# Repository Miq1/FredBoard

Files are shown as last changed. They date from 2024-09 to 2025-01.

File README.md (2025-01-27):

### FredBoard
FredBoard is an alternative firmware for the Irijule TheoryBoard written by [frudah](https://github.com/Frudah). It has no connection with the original Irijule firmware but was written from scratch. While using the same hardware it has a number of additional features not found in the original.

While FredBoard is closed software for now, this repository is targeting at user exchange, additional (hardware) modifications and bug tracking.

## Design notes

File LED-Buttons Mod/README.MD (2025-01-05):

# The LED buttons mod
This modification will replace the top row buttons of the Theoryboard by RGB LED-lit ones the FredBoard firmware is controlling.
Initially the left button row is serving as a reference of the note colors, whereas the right button row will indicate the color of the currently selected root note.

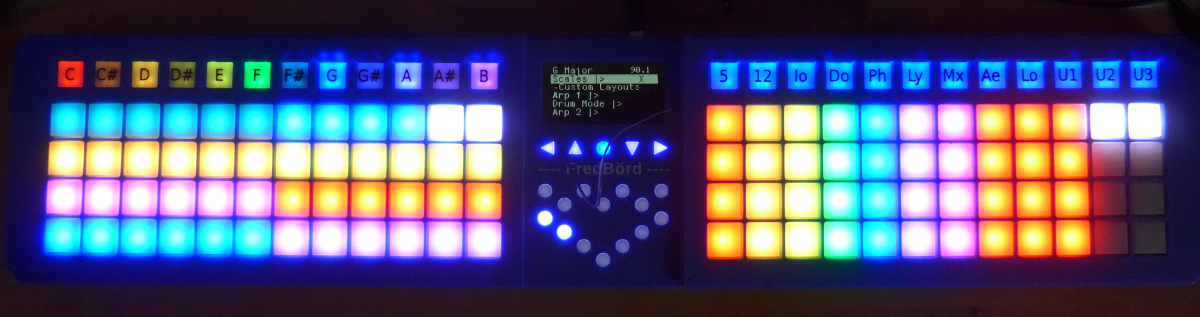
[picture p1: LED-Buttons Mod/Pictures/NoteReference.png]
Example lit board


## Some remarks before you start - please read!
This mod is a slightly complicated one and has several caveats to consider:

- it will make sense only if you are using the FredBoard firmware that controls it
- it will require some soldering skills as well as the ability to work in very small dimensions
- it will require you to solder on the Theoryboard's main PCB with a risk to damage it
- it will need permanent modifications to the Theoryboard's case - holes being cut into it
- it will cost you about 50 bucks for the materials used - more if you break something...

On the plus side you will gain some benefits:

- A much better visibility of buttons and their functions
- a case lid that is really sturdy, much more than the original
- the ability to choose a color you like
- overall a unique board no one else has

Note that this modification is including both the "Top Row Mod" and the "Center Panel Mod" in modified form.

## Update V1.1
- I modified the STLs for a better fit. All instructions remain valid, just the 3D prints are different.
- I added some pictures of the different lettering on the buttons (center/ragged left, lit/plain, main text only/second text added).

## Requirements
### Materials
#### Case lid

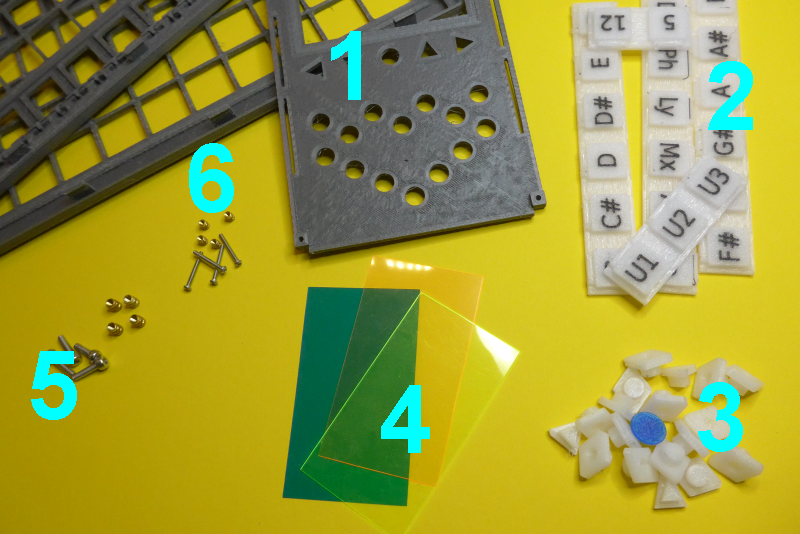
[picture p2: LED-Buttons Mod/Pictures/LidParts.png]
Materials for the lid


1. 3D printed components for the plastic lid.
Note that a 3D printer is required that is able to print a 300mm wide and 150mm deep part!
2. 3D printed top row buttons - requirements as described in the "Top Row Mod" instructions (TPU, best with IDEX printer)
3. 3D printed center panel buttons - requirements see the "Center Panel Mod" instructions
4. Screen protector/filter sheets as described in the "Center Panel Mod" as well
5. 4 M3 melt-in threads and 4 matching M3x12 screws.
Cylindrical screw heads advisable.
6. 4 M2 melt-in threads and 4 matching M2x16 screws.

#### Wiring and electronics

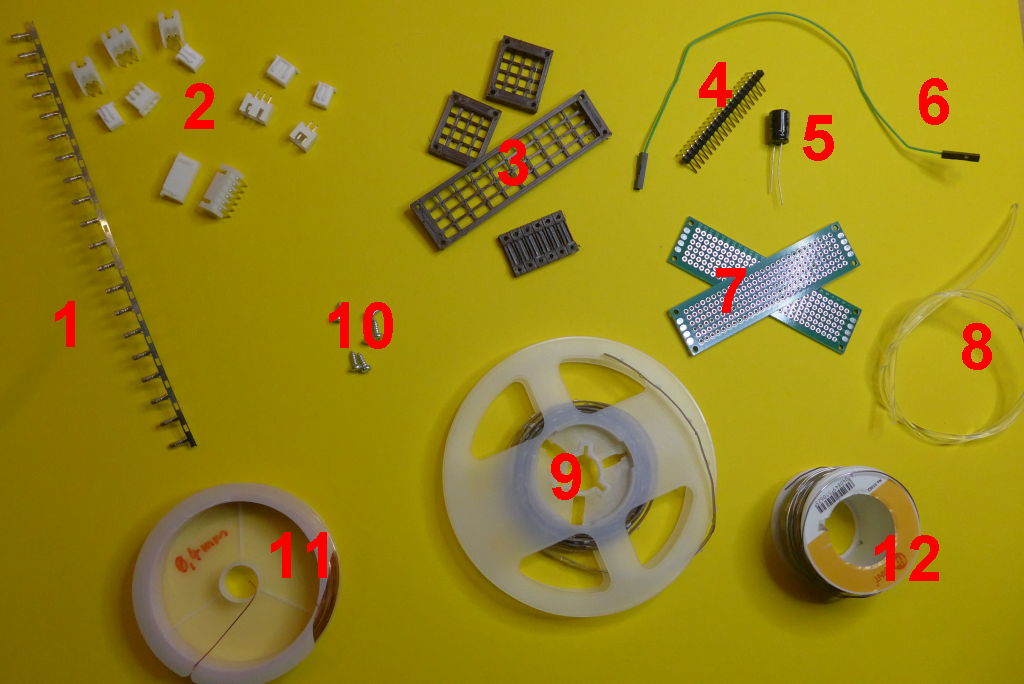
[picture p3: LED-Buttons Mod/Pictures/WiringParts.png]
Materials for wiring


1. Crimp contacts for JST XH type connectors
2. JST XH connectors 
    - board connectors (male): 
        - one 6-pin angled 90°
        - one 3-pin angled 90°
        - two 2-pin angled 90°
        - one 3-pin straight
        - one 2-pin straight
    - cable connectors (female)
        - two 3-pin
        - three 2-pin
        - one 6-pin
3. 3D printed PCB holders and cable clamps
4. some angled pin headers
5. a 470µF, 16V electrolytic capacitor
6. 20cm female/female Dupont patch wire
7. 2 2x8cm PCB universal prototype boards
8. 60+ cm of 2mm diameter PMMA fiber ("side glow")
9. 100+ cm of 3mm wide, 5V, 60 LED/m WS2812B LED stripe. 2m or more are not that expensive and will help if you break some... 
    - Example from aliexpress.com:
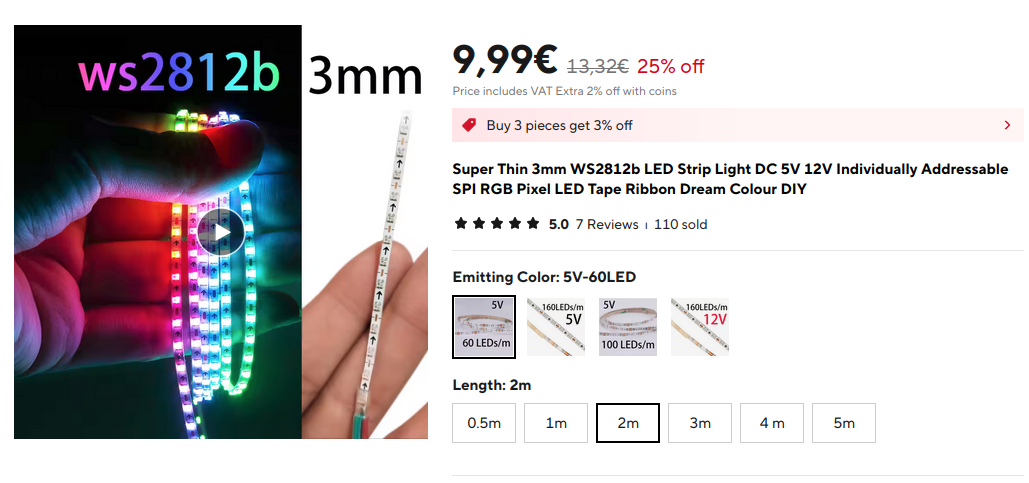
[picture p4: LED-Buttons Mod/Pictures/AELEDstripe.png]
Example LED stripe
    
10. 8+ 2.2x4mm self cutting screws
11. Enamelled 0.4mm wire
12. A good quality solder

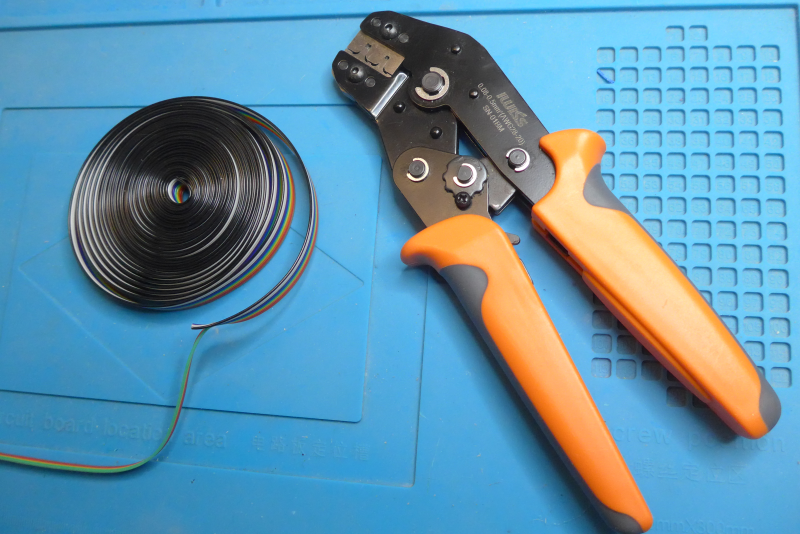
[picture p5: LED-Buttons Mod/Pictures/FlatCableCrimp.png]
Flat cable and crimp tool


* a length of AWG 24 flat cable - 5 wires at least
* (a crimp tool suitable for JST XH contacts)

### Tools
* a fine soldering iron or workstation
* a 3D printer capable of printed parts 300x150mm and able to print TPU. IDEX printer preferred for the two-color buttons.
* a multimeter for testing
* (optional) a heat gun or better a reflow workstation (recommended)
* a hot glue gun
* tweezers
* (optional) a Wemos D1 mini or NodeMCU board for testing

## Disassembly
Please refer to the "Center Panel Mod" and "Top Row Mod" instructions for the initial disassembly and removal of the printed original cover sheets on center panel and button rows.

In addition you will need to remove the PCBs. 
The center board is held by 4 screws in the corners of the board.
The two keyboard PCBs have 4 larger screws in their corners and 8 smaller ones on top and bottom of the boards.
Remove all to completely loosen the boards.
Put the screws at a safe place to later find them again...

The left and right keyboard halves are connected to the main board by flex cables.
Be careful not to bend these cables or break them! 

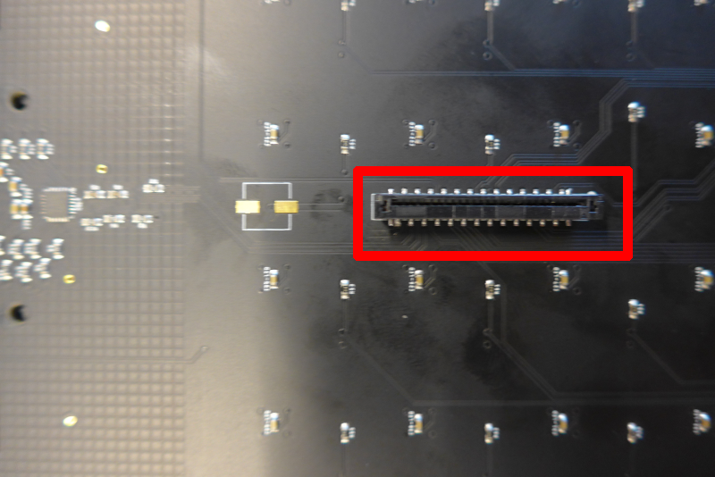
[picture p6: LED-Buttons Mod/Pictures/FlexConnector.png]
Flex cable connector


These flex cable connectors have a rectangular lock sitting around the flex cable.
To release it, gently pull the lock out of the connector.
It will not detach from it completely, but just move up a few millimeters to unlock the flex cable.
You can pull out the flex cable without force once the lock is released.

I would suggest loosening the flex cables on the main board side only and leave them connected to the keyboard PCBs to not displace or switch them.

Put the keyboard PCBs aside to a safe place.

## The Lid
We will replace the original case lid with a new, 3-part printed one.
It consists of the left and right keyboard sections and a center plate.
You will find the STL files for these parts in the "3D STLs" folder; the files are:

* ``TBLid-LeftKB.stl`` for the left,
* ``TBLid-RightKB.stl`` for the right keyboard halves and
* ``TBLid-Plate.stl`` for the center panel

You may print these parts with any hard filament you like, I recommend using PETG or even ABS for better UV resilience.

Note that lighter colors will tend to let the LEDs shine through. 
I suggest to put some black acrylic paint over the affected areas to reduce the effect:

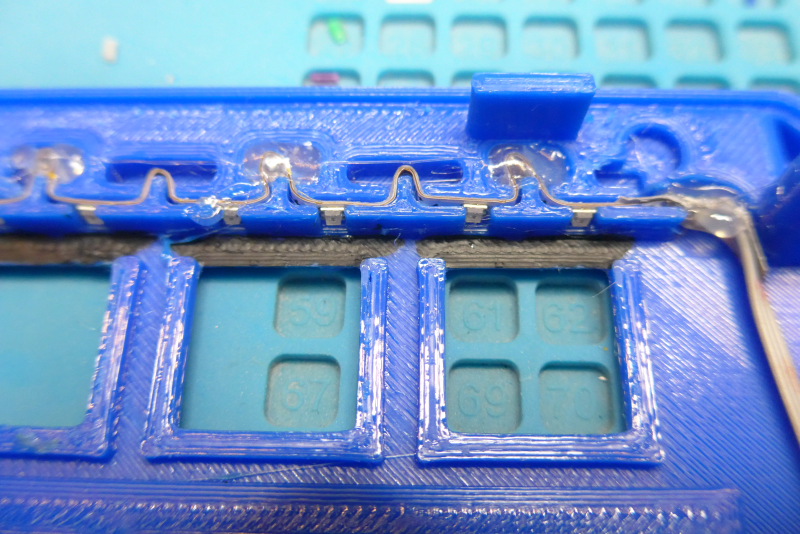
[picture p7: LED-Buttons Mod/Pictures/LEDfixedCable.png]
Areas painted matte black


Note also that the center panel has two long slits on either side that will match the two rims in the keyboard parts.
With the final assembly we will join all three parts with these.
Do not try to join the parts prematurely (before the LEDs are installed) because the fit is **very** tight and may not be loosened again without breaking it.

Finally insert the melt-in M3 threads into the 4 cylindrical columns (2 each on either lid half).
Be careful not to deform these columns when warming up, they need to fit into the corresponding holes in the lower case tray.

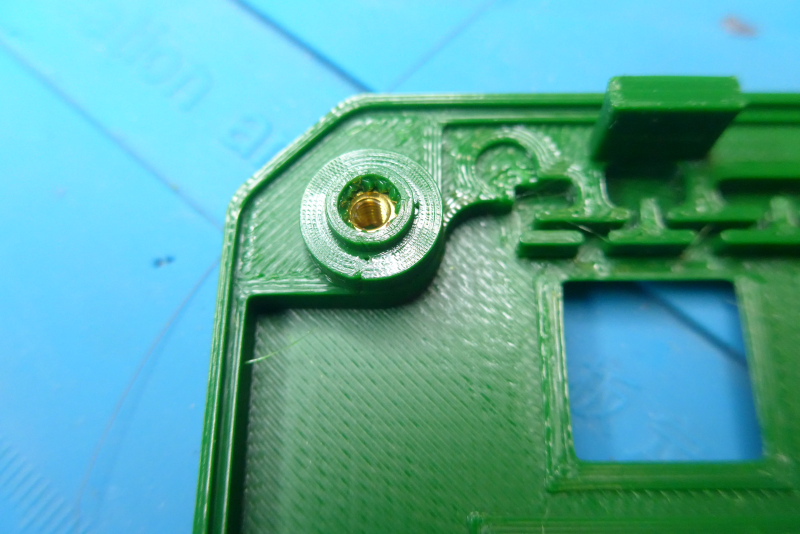
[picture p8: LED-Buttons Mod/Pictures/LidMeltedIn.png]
Threads melted in the lid


## The Buttons
As is described in the "Top Row Mod" and "Center Panel Mod" instructions, print the buttons from TPU filament to keep them flexible. 
Print the center panel buttons in any translucent color you like, as the LEDs beneath it are all white. 
A translucent white TPU is highly recommended for the button bases to let the colored LED light shine through unmodified.

### OpenSCAD Script
In the "3D STLs" folder you will find an OpenSCAD script named ``LitButtons.scad``.
You will need to install the OpenSCAD tool to use it - it is Open Source and can be found at [the OpenSCAD Home page](https://openscad.org/downloads.html).

Be sure to have the Customizer visible in it; it can be displayed with the 'Customizer' entry in the 'Windows' menu.

In the Customizer you will find all modifiable parameters to generate the buttons to your liking:

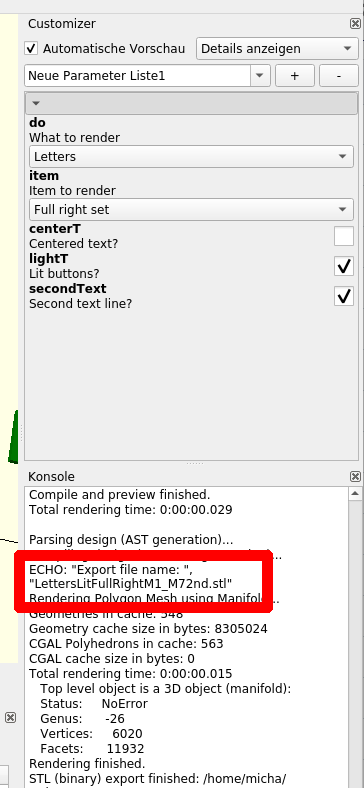
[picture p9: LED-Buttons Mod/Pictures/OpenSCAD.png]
Customizer menu


``do`` needs to be set to both 'Letters' and 'Buttons' to generate the two respective STL files in a separate run each.

``item`` lets you choose which set of buttons you want to have generated.
Note that the 'Full set' items will require a printer with a print bed at least 270mm wide!
If you have a smaller printer only, I recommend to print the shorter button sets instead.

``centerT`` will have the main text centered on the buttons if the tick mark is set.
The text is left bound else.

``lightT`` should be marked for this mod. 
It will generate the necessary light tunnels etc. on the buttons that are needed for lighting.
If unchecked, buttons for the plain top row mod without LEDs will be generated.

``secondText`` will reduce the main text in size and put a right bound second text below it.
This second text is the alternative note names on the left side and a digit sequence plus 'bsp' and 'sep' on the right side. 
These are used for the FredBoard firmware in certain cases.

The rendered picture in OpenSCAD will show you the resulting objects after you modified any value.

The get a valid STL from this result, you will need to first press the **F6** key to render the objects again in a finer structure, then the **F7** key to save it as a STL.
A recommended file name based on your chosen parameters will be shown in the Console window as indicated above with the red frame.

The LEDs are placed at the sides of the buttons.
To improve the lighting the buttons have two 2mm light channels each in them that will be used to transport the light to the far sides of the buttons as well.
This is achieved by inserting short segments of PMMA fiber into the channels.

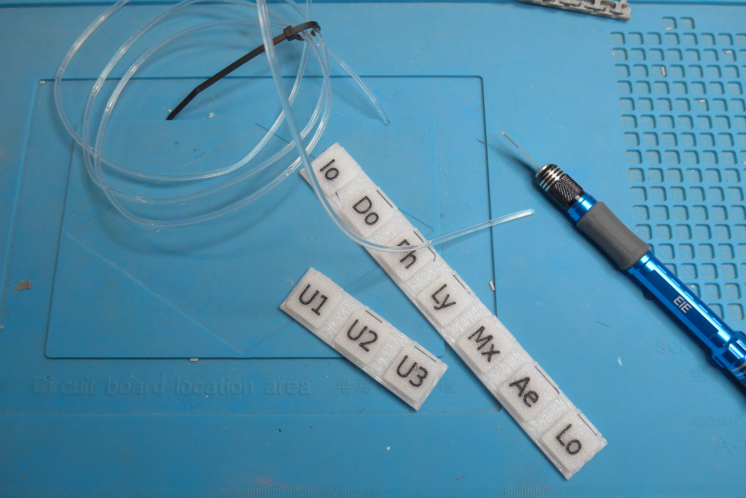
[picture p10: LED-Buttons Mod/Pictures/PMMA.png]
PMMA and tools


Push the fiber into the channel as far as possible, the cut it cleanly with a sharp scalpel.
The more even the cut is, the better the light will be passed through.

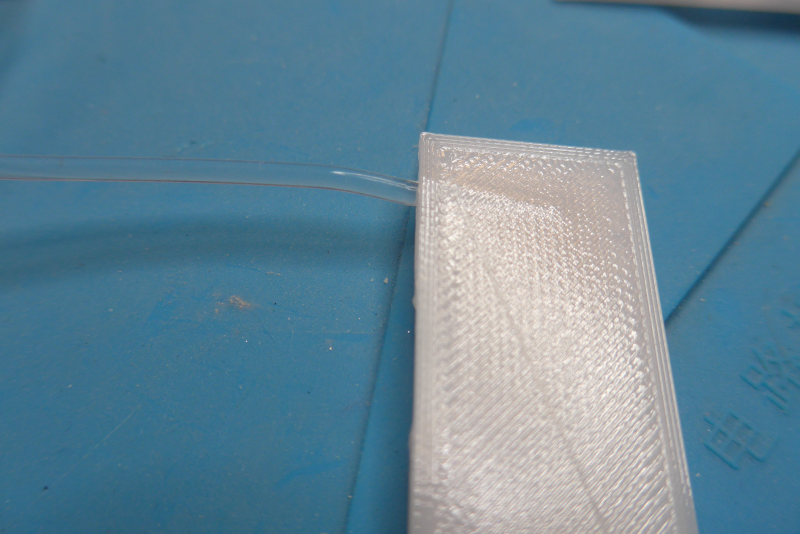
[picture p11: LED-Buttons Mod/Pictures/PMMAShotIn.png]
PMMA pushed in


Do not yet insert the buttons into the keyboard parts before the LED stripes have been installed.

## The Wiring
We will take all needed signals and power from the main board. 
With one exception all are available on solder points that are easy to connect.
These main board wires will go to a "rail board" tha sits under the main board and will distribute the signals to the LED stripes and the flash button (optional, see below).

The schematics is simple:

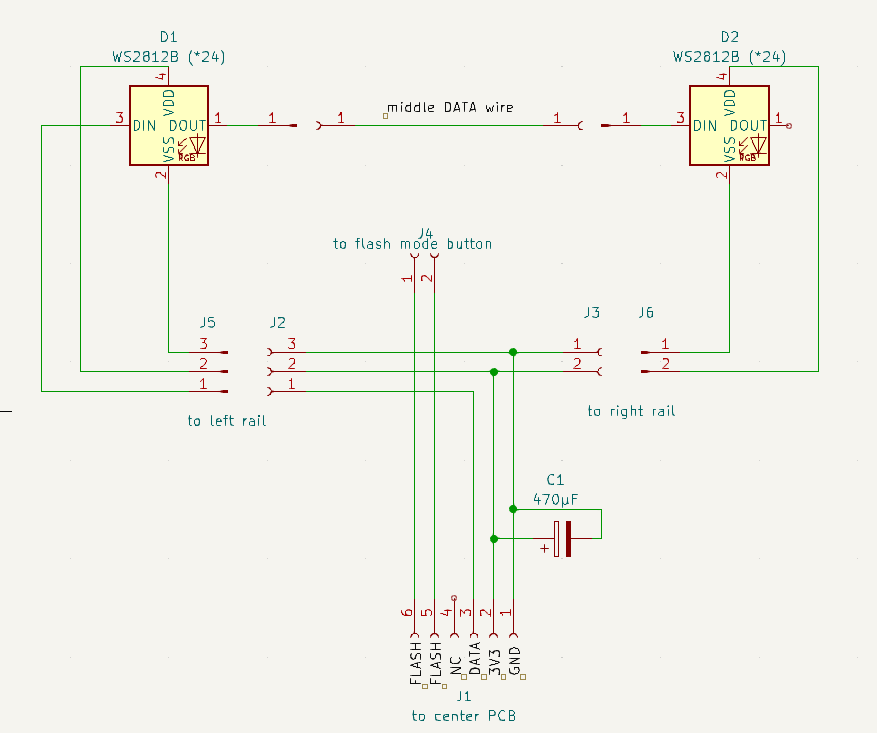
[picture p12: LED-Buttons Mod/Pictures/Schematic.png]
Wiring schematics


The connector from the main board has GND, 3V3 and the DATA IN signal for the LED stripes, plus two wires that, when shorted at power up, will set the board into flashing mode.
This is purely optional, if you do not want the flash button extension, leave out the two wires completely - but be sure to connect the other three as are seen in the schematic and wiring.

The capacitor is to stabilize the power supply of the LEDs.
Newer Theoryboards will have the same type of capacitor sitting below the keyboard PCBs (large pads close to the flex cable connector, minus is the upper pad) for the same reason.

The power lines are split into two sets of wires to supply each side independently, whereas the DATA IN line is only directed to the left keyboard'S LED stripe.

The general order of LEDs is from the far left to the far right. The DATA IN signal is guided through a single wire between the left and right stripe running below the center plate.

Keep this in mind! 
If you happen to miss this order at some point, the stripes may not work at all or at least are not lit correctly by the firmware, that is relying on the order described.

You will see that most LED stripes have arrow symbols printed on that will give the direction the stripes' LEDs are ordered. We will need the arrows are strictly pointing to the right.

### Three PCBs
We will build three small PCBs. 
One center "rail board" and two small connector boards to the left and to the right.

I am preferring designs that will allow a separation of components if necessary in the future, so all the PCBs are connected by JST XH type sockets and plugs.
You may solder the wires directly if you prefer, but I strongly advise to at least leave in the 6-pin connector between main board and the rail PCB to be able to restore the Theoryboard to almost its original state if needed.

The rail board has 90° angled JST XH connectors - else it will not fit below the main board any more.
These angled connectors are not to be found in the common sets of JST XH connectors, but must be ordered separately.
The set boxes will have straight connectors only.

**Be sure to always maintain the order of wires GND, 3V3 and DATA IN!**

#### The Rail Board
I took one of the 2x8cm prototype PCBs to set up the rail board.
This PCB will fit neatly into the lower middle compartment of the case tray (after some preparations described further down).

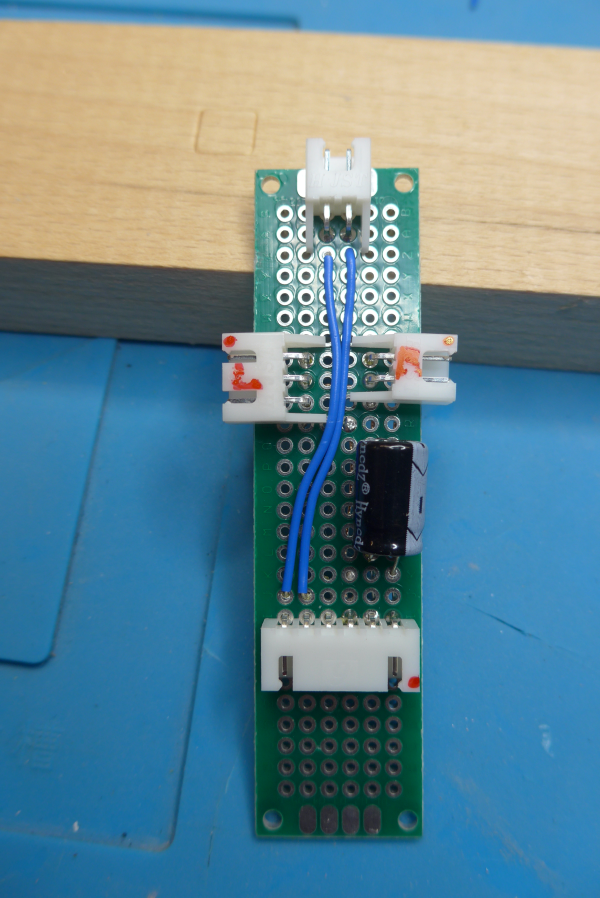
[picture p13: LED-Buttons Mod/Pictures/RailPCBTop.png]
Rail board from top

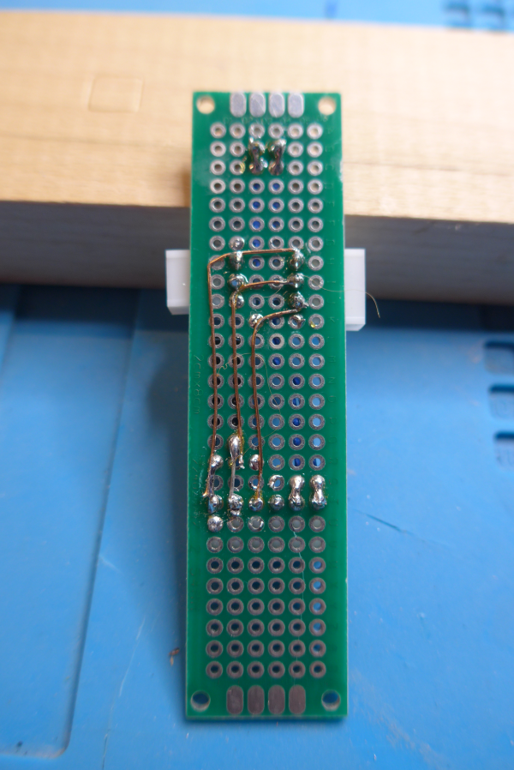
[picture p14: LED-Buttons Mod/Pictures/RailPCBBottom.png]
Rail board from below


As you can see I used enamelled wire to construct the traces. The capacitor must be placed lying sideways to again fit under the main board.

It is advisable to use the exact same layout to have the connectors accessible when the board is mounted into the case tray.

#### The Connector Boards
The left (3 pins) and right (2 pins) connector boards are very similar.
A plug and a approx. 36cm ribbon cable are the connection to the rail board, whereas the other end of the cable will be soldered to a small PCB with a matching straight JST XH connector on it.
These connectors will accept the plugs from the respective side's LED stripe.

3 PCBs

**I cannot emphasize enough to maintain the order of pins!**

I used the 3D printed cable clamps (``CableClamp.stl`` in the "3D STLs" folder) with two of the angled pin headers to secure the ribbon cables against being ripped off.
This may be overly cautious - you may decide to omit that.

I recommend to use a multimeter frequently to make sure all connections are correct and no short has been introduced.

#### Mounting Plates
I like to fix such additions to an existing device with hot glue.
In case you need to remove it again, a hot air gun is sufficient to heat the glue to get it off the ground.
Hot glue is mostly fine, but adhesion may not be the best depending of the material it is applied to.
This is why I designed mounting plates for the three PCBs that have the right dimensions to fit and have a grid structure at the bottom side to nicely be filled and held by the hot glue.

Print files are again in the "3D STLs" folder, named ``PCBsocketLarge.stl``and ``PCBsocketSmall.stl``, respectively.

The mounting plates can be fixed to the PCBs by the tiny 2.2mm screws through their holes in the corners.

### Wiring the Main Board
**This is the point where you may accidentally damage the main board - take utmost care to only solder to the points as described!**

Please see the following picture of the main board for the remarks below it:

Main board wire connections

A 12cm ribbon cable with 5 wires (3, if you do not want to have the flash mode button) is used to connect to the main board.
It is advisable to crimp the 6-pin JST XH plug before soldering the other ends to the main board to prevent strain on the freshly soldered connections.
On the picture you see my colors used for the different signals:

- red for 3V3
- brown for GND
- orange for DATA IN
- yellow and green for the flash connection

With the exception of DATA IN all wires can be cut to length and soldered to the indicated soldering points.

DATA IN is available only at the indicated pin of the flex cable connector.
With a tiny drop of solder you should be able to fix the DATA IN wire to it.

I like to secure the ribbon cable with two drops of hot glue to the main board.
When routing the cable, avoid the white dots marked with a green circle around it: these are the spots where the support struts from the case tray will touch the main board.
The green vertical line is marking another support structure of the case tray that we will have to open later at exactly the spot where you laid the ribbon cable.

### Modifying the Case Tray
To make room for the wiring and PCBs the case tray needs to be opened at several places.

Note that this is irreversible as you will be forced to remove material from the case tray.

The main modifications have to be made underneath the main board:

Cutouts at the case tray

At the area marked "1" we need to cut a hole to let through the plug from the flash mode button - should you decide to want it.
You can see the (blurry) blot of hot glue where I mounted mine in the back.

The "2" marks the area where the freshly soldered ribbon cable will run under the main board.
The traversal structure needs a 1-2mm opening here to let pass that cable.

"3" and "4" are marking the inner edges of the supporting struts that must make way for our rail board.
These inner edges of the X-shaped struts need to be removed completely, making the struts' profiles to a "T" shape.
The edges have to be removed down to the bottom, making a flat surface there.

I used a Dremel tool with a cutting disc to remove all these pieces.

In addition to the modifications show on the picture we need thin slits in the blocking walls towards the left and right outer walls of the case tray to let pass the ribbon cables leading to the connector boards.

Again I used the Dremel tool to cut small openings - just one disc thickness wide and just as deep as was necessare to get the ribbon cable through.

### Placing the Boards
Now that everything is prepared we can install the three boards.

The rail board should neatly fit into the opening we created between the struts:

Rail PCB placed

Note the openings marked with red rectangles.

Now is the time to also melt in the M2 threads into the openings marked green.
These will later accept the M2 screws used to hold everything together in the middle.
Again take care not to deform the the cylindrical columns when warming those with the heated threads.

As an example for both sides see the placement of the left connector board below.
The cables are running through the opened walls, the board is placed immediately adjacent to the outer wall of the case tray.
The connector is on the side pointing outwards - when the keyboard PCBs are back in place there will be a gap leaving the connector accessible.

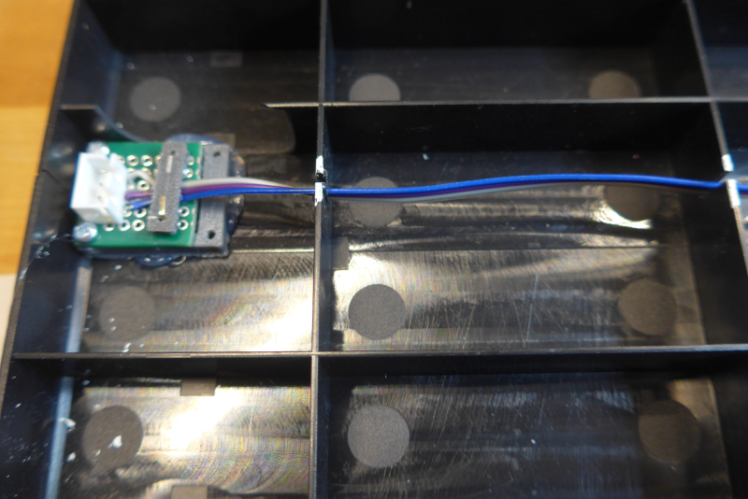
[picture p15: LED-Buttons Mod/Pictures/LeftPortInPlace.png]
Left connector board placed


(The inner wall next to the board was broken already when I got my Theoryboard...)

All three boards now can be fixed in place with a good portion of hot glue.

## Reassembly of the Case Tray
Now that the lower part of the wiring is inplace, we can put most components back together.

- reconnect the keyboard PCBs to the main board, using the flex cables. 
Be sure to use the correct orientation of cables if you had completely removed those.
The flex cable connectors' locks will fall in place again when pushing these gently towards the boards until you will feel a slight clicking movement.
- put the PCBs back into the case tray.
- use the 8 larger corner screws to fix the keyboard PCBs (4 each)
- **do not fix the main board yet**
- add the 8 bottom screws with smaller heads to additionally fix the keyboard PCBs.
**Leave off the 8 top screws (4 each) as are marked on the picture below**

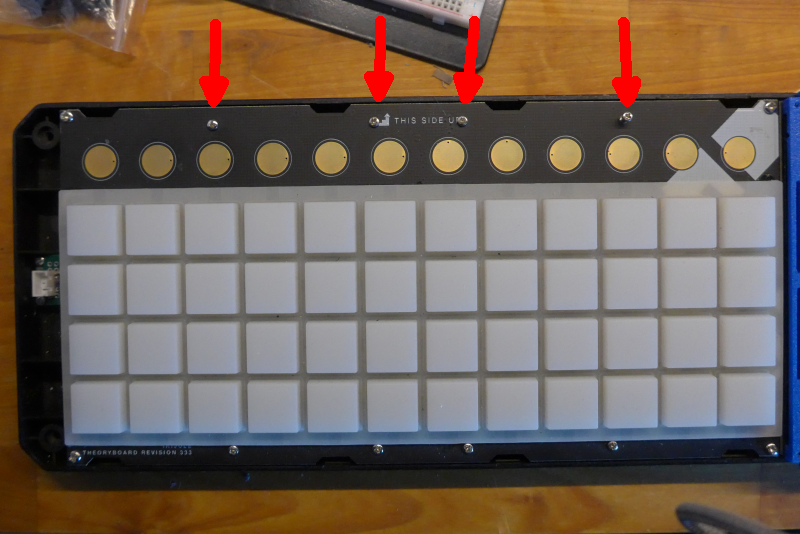
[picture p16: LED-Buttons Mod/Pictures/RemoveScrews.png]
Screws to leave off


## The LED stripes
This step is that with the most difficult procedures.
Take your time and act cautiously.

Since the LED stripe has a 60/m measure, meaning 60 LEDS are evenly distributed on one meter of stripe, their distance of 16,667mm is not suitable for the distances our board will need.

The technique used to achieve the distances for the buttons is to loop the stripe between the LEDs proper in different lengths.

The LED stripe not only is really narrow, the LEDs and their connections to the stripe are not very robust.
A single broken connection will render the stripe useless for our purpose.

Thus utmost care must be taken to not bend the stripe too close to the LEDs to prevent them to break off.
The stripe material itself is tolerating some rough treatment, though, so if you need to force a bend, do so at the plain stripe.

As said before, the stripes have a direction, indicated by arrows printed on the stripe.
You need to maintain a direction of left-to-right (if seen from above the Theoryboard) throughout the stripes' installation.
**You will have to install the stripes from the bottom side of the lid parts, so keep in mind the directions will be reversed!**

### Wiring the Stripes
For each stripe we will need 24 LEDs. 
These 24 LEDs must be consecutive on a piece of stripe that is native - no modifications made to it.
I have to explicitly state that as I learned that the vendors seem to join shorter pieces of stripes to form a longer one by soldering them together.
On the picture below the red arrow is pointing to such a soldering point.
We can not use these mended stripes as they will tend to break when bent at the soldered joints.

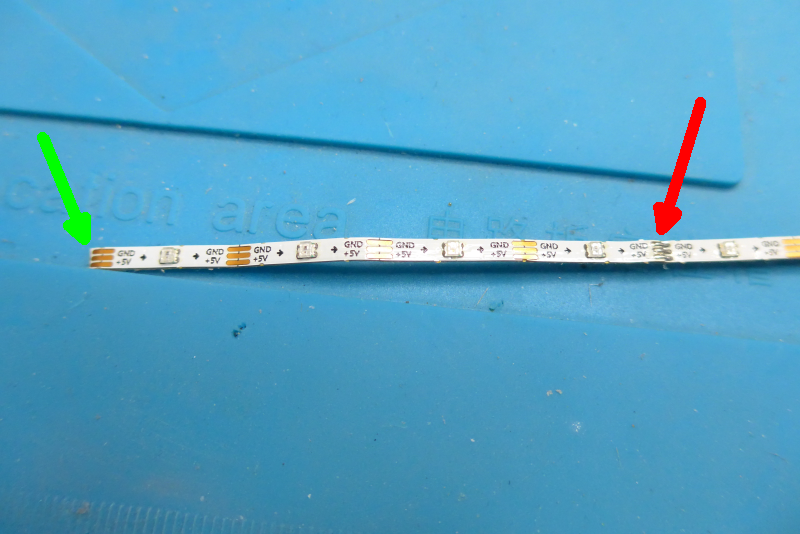
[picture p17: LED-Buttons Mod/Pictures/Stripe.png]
Example stripe


The green arrow pointing to the left end of the stripe indicates a cut made by me.
I recommend to cut at the beginning of a 3-trace contact area, hence sacrificing the LED before it.
You will benefit from the longer traces when soldering a ribbon cable to it.
Same holds true for the end of the 24 LED segment.

Note also the tiny arrow symbols on the stripe indicating the direction, and the order of signals at the connectors:

* top: GND
* middle: DATA IN
* bottom: +5V - specified voltage, we will be using 3V3

I strongly advise to cut, tin, trim and crimp the cables before soldering these to the LED stripe.
Even if you may lose the work when breaking something afterwards, preparing the cables will protect the stripes from being broken by rough treatment.

#### Leftmost Cable
On the far left side we have a 3-wire ribbon cable that will be plugged into the left JST XH socket and connect to the left end of the stripe on the other end.
A 9-10cm length of ribbon cable will be sufficient to connect to the socket.

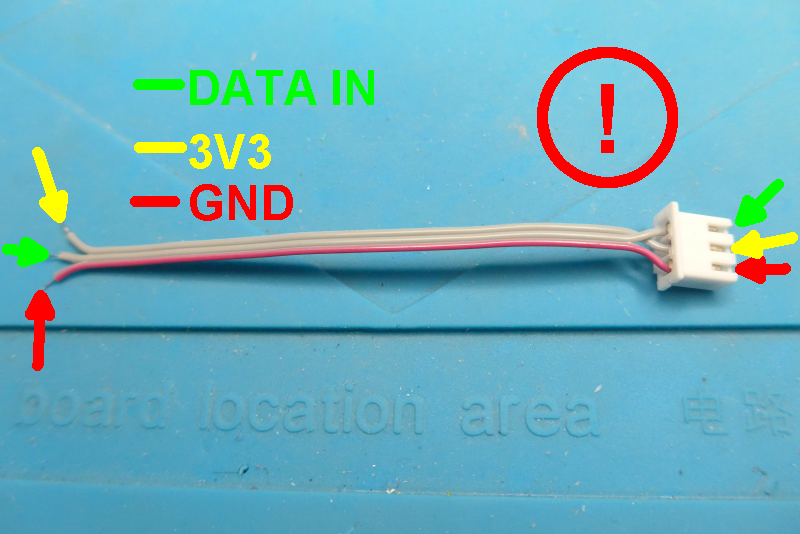
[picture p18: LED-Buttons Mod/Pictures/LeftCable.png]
Cable for left stripe on left side


**Note that the DATA IN and 3V3 wires need to be crossed at the connector to maintain the order of the internal wiring!**

Having the prepared cable ready as seen on the picture, first with a hot soldering iron tin the three contact pads on the stripe.
Try not to put excess tin on it to prevent a short that is hard to remove.

Soldering is best to be done with a "third hand" tool fixing the parts to be joined in place.
The connection will not stand any bending or pulling, so try to avoid these movements completely to the end of the work on it.

Next with a swift touch of the iron solder the middle DATA IN wire to the middle pad.
It does not need to be overly fixed, a small unbroken connection will do.

With a multimeter check if you produced a short between any of the three pads before proceeding.
The best way to get rid of a short is to unsolder the wire again, remove most of the tin on the pads and try again.

Next bend the outer wires to their target pads one by one and again with a swift touch fix each on the respective pad.

With the multimeter check for any shorts again.
There must be no connection between any of the pads.

#### Interlude: the Test Sketch
I found it handy to always check if the stripe was working while I was on it.
I wrote a small test sketch running on an ESP8266 MCU that will drive the connected stripe to show some test patterns.
You will find the sketch code in the "Test sketch" directory with a few explanations in the enclosed README.MD file there.

No would be the first sensible point to put it into action to see if the stripe as is will work.

#### Leftmost Cable continued
If the stripe is working, we can fix the connection to further prevent breaks or shorts.
I normally will use a drop of "Pattex Repair Extreme" glue - an acrylic glue that is viscous and will fill the tiny gaps between the ribbon cable and the stripe.
Once that is applied, I additionally will put a short piece of heat shrinking tube over the joint and let it shrink with a heat gun.

The result:

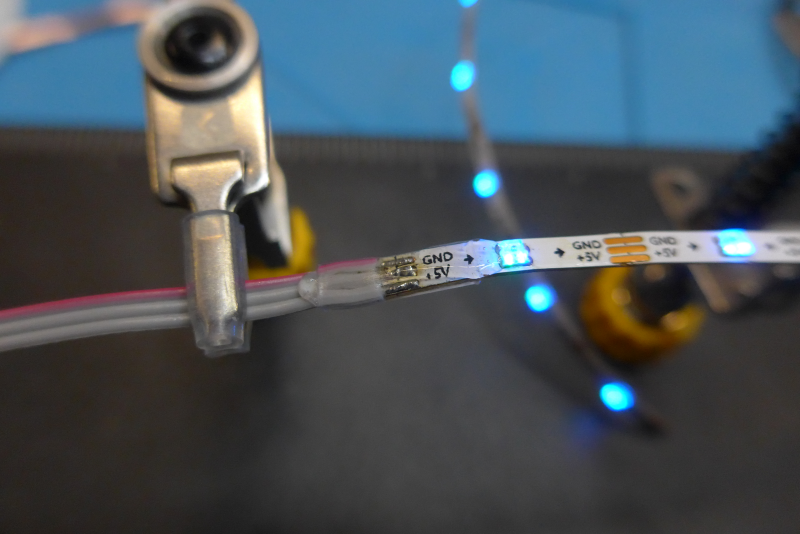
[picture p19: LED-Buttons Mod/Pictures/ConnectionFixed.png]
Connection with glue and shrunk tube over it


If you came here with success, take a break now and let the connection harden for some hours!

#### Left Stripe, Data Pin
Next we will take care of the DATA IN connection that will be located on the far side of the stripe, opposite to the connection we just made.

There we will need the middle pad on the stripe only and solder one angled pin header to it.
The longer leg of that pin header shall point out from the stripe in the direction the LEDs are facing.
In the end the single data wire across the center plate will connect here.

First of all shove another short piece of heat shrinking tube from the far end over the stripe, as you will not be able to do that any more as soon as the pin header is soldered.

Next put a little bit of tin on the middle pad of the connector at the end of the stripe.
Try to not hit the adjacent GND and +5V pads if possible.

Remove the plastic frame from the pin header, so that you get the metal part only. 
With a soldering iron put some tin on the short leg of the header.

If you have a very fine brush and acrylic paint at hand, try to cover the GND and +5V pads with it to provide a minimal isolation,
Do not touch the tinned middle pad with it.

Now with a swift touch of the iron again solder the pin to the stripe pad.

With the multimeter check if there is any short between the pin and GND or +5V.

If all is still working, you may secure the pin on the stripe with the technique as before: put a drop of glue on the joint, shove over the heat shrinking tube and shrink that with a heat gun.

Again the result:

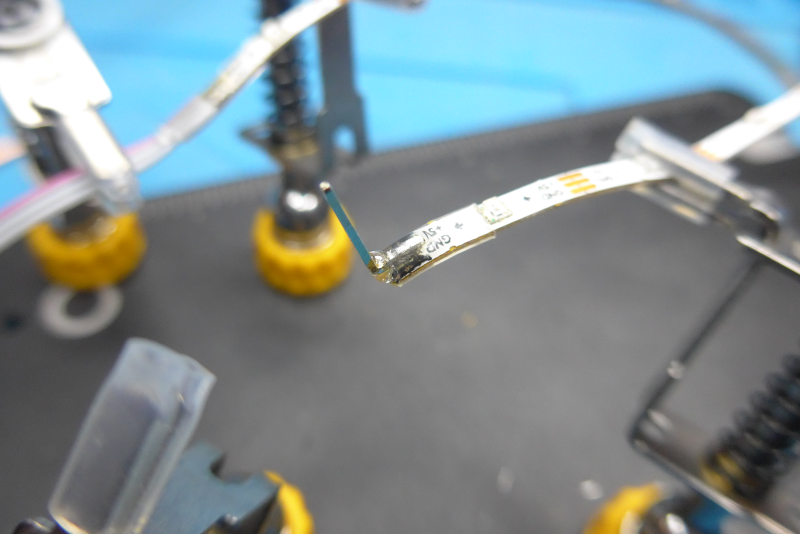
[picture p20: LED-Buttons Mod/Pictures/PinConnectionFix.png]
Header pin with glue and shrunk tube over it


#### Right Stripe, Data Pin
The right LED stripe has to have the single DATA pin on the left hand end that will get the signal from the similar pin on the rightmost end of the left stripe.

Be sure to have the little arrow symbols pointing away from the pin to get the right order of LEDs.

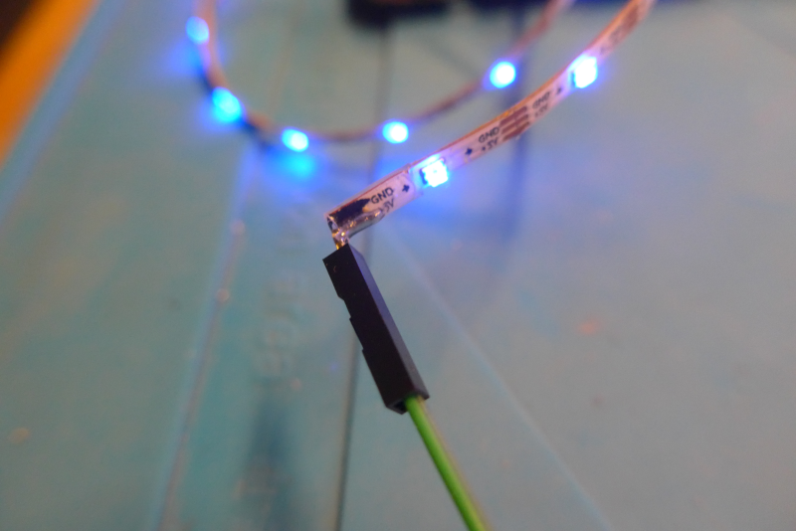
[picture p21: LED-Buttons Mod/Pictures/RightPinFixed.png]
Right stripe data pin in place


#### Right stripe, connector cable
Finally the right end of the right stripe has to get its 2-wire ribbon cable with a 2-pin JST XH plug.

The same techniques are applied here: prepare the ribbon cable including the plug first.
Take care to maintain the order of wires for the socket - GND and 3V3 must not be swapped.
Think thrice before fixing it...
Next tin the two outer pads on the stripe and cover the middle with acrylic paint if you can.
Solder the ribbon cable to the stripe pads, again checking the order of signals.
Finally - after testing the stripe - put some glue on the connection and cover it with a heat shrinking tube.

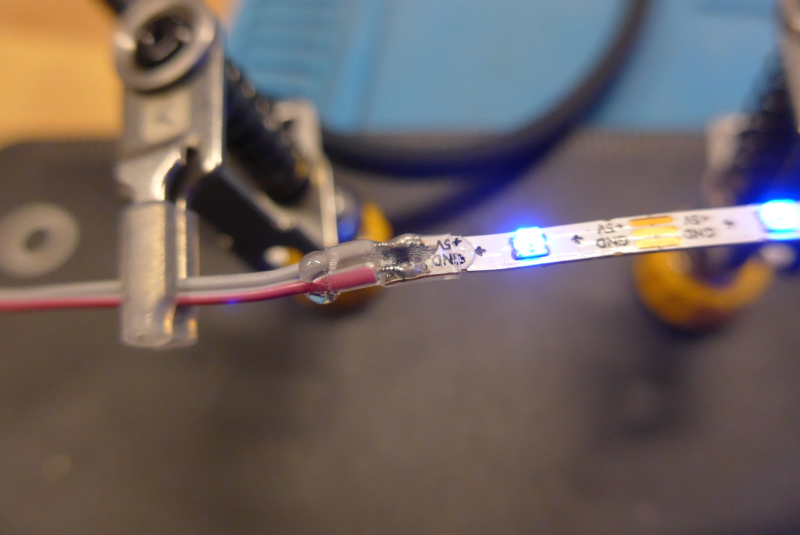
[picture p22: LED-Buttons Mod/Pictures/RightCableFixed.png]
Right stripe ribbon cable in place


### Inserting the Stripes
Now that the wiring is done, we will insert the stripes into their respective lid halves.
Remember that the left part has the 3-wire ribbon cable leftmost and the pin in the middle, whereas the right part has the 2-wire cable far right and again the DATA pin in the middle.

If you will look at the inner side of the lid parts you will notice a complicated meandering structure at the upper edge.

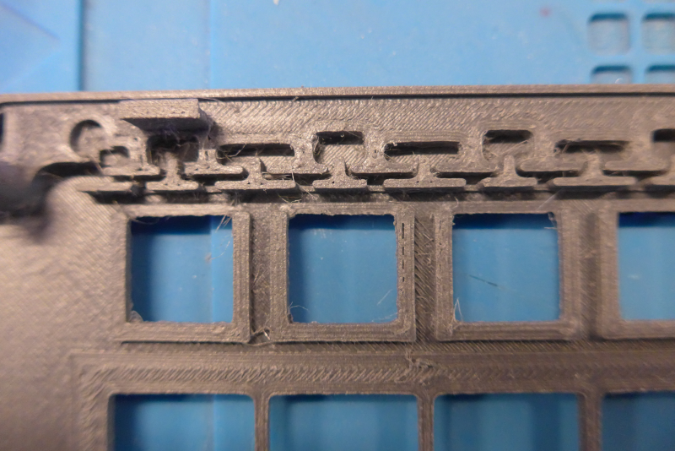
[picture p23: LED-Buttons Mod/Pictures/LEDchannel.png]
Structure to hold the LED stripe


The structure has segments shaped like a inverted "T" in the bottom row and "bubbles" on top of each T.
The T shapes have two alternating sizes, a narrower T for the spacing between the two LEDs for one button and a wider T for the spacing between two buttons.

You will notice the "bubble" on top of the narrower T always is larger than that on top of the wider T. That is because the bubbles need to hold the excess stripe material and a narrower distance between LEDs results in more stripe to be held.

Starting on one side we will insert the LED stripe in such a way that the LEDs are placed in the gaps between the Ts and the stripe will be looped through the bubbles between the LEDs.

**A word of caution again: the stripe sections immediately to the left and right of a LED must not be bent to prevent a break-off of the LED!**

I found it handy to use a small tweezer to grab and bend the stripe at the right spots in right angles, but gently push it into the structure with a finger only.
If a LED does not yet fit into its gap, gently pull the previous loop in the previous bubble a bit to set it right.
Finally I used a rounded plastic tool to push the stripe at the bent corners deeper into the structure.
At all times I let the stripe connected to the test ESP8266 to immediately notice if I had something broken.
That did happen a couple of times during development - I had to spend about 2 meters of LED stripe until I had finished two complete sets.
I got better over time...

When the stripe is set into the structure, it should look like on the picture below - and still be working.

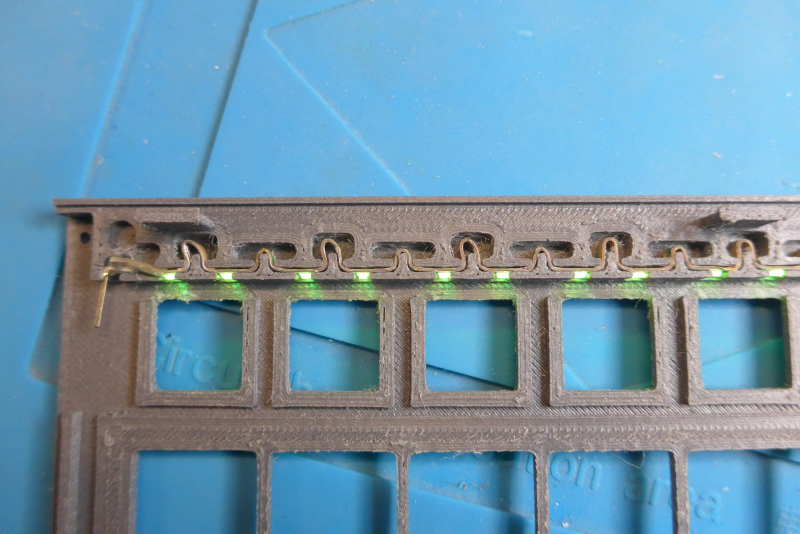
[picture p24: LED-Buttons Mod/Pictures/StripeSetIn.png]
LED stripe inserted


Finally you can fix the stripe additionally by filling the larger bubbles with hot glue:

LED stripe fixated

## Reassembly Part 2
Now you can squeeze the TPU buttons in their holes below the LEDs.
The fit is **very** tight on purpose.
The best way to get the buttons in is to first press the side with the PMMA fibers against the LED row and into the button openings.
Then with some force but carefully try to press the lower side of the buttons in.

After the procedure the buttons must be flush with the LED frame:

Buttons are even with the LED frame

Next insert the data wire into the channel on the bottom side of the center panel.
Try to have the ends of even length.
I used a rounded plastic tool to press the cable in.
It will hold without any glue.

DATA wire set into the center panel

Finally we must join the three parts of the lid.
There are two slits on each side of the center plate where the 2 edges of the keyboard parts must fit in.

The fit is overly tight on purpose, since any 3D printer will have its own tolerances.

With a flat file you will have to remove some material at the areas marked red in the picture below:

Areas marked to be filed to fit

Do not overdo - rather file, try, file again etc. until you will get a very precise fit.
depending on your printer you may have to file the inner or outer rims of the slits.
Best try first by holding the center plate in place to find which direction will suit you better.
A perfect fit will hold the parts together without any glue.
This is advantageous if you later decide to have a different center plate or need to repair one part.

If all else fails or if you feel better with it, you of course can put a few drops of acrylic glue (or whatever sticks best to the filament type you chose) on the joints to secure them.

If the parts are neatly connected, plug in the DATA wire on both keyboard sides (as seen for the right keyboard side on the picture above).

## Final Assembly
Place the screen protector/filter on the display and set all center panel buttons into their places.
Now lift the joint lid on the keyboard and connect the two ribbon cables to their sockets.
Gently nudge the lid in place:

- the center panel buttons must glide into their openings in the center plate
- the keypads must fit into the grids
- the clamps at the outer edges of the lid must go into the openings in the case tray
- the 4 corner struts with the melt-in threads must slip into the cylindrical holes of the tray

You may need to wiggle and nudge a lot until all is matching.

Use the 4 M2 screws to fix both center plate and overlapping keyboard halves to their thread down in the tray.

Flip the board over, holding the outer sides of lid and tray pressed together witch your hands.

From the bottom side fasten the 4 M3 screws into their holes in the corners of the tray.

Flip over again - it is done!

Congratulations!

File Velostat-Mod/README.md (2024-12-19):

### Why another Mod?
My original Irijule keypad on the right hand side was defective.
Over time one key ceased working.
I opened the keypad to find the cause but did not detect any obvious.
The conductive coating on the keypad foil seems to have lost its conductivity somehow.

From a former project I still had a sheet of Velostat - a conductive plastic film that changes conductivity when pressed, torn or stretched.
So I gave that a try to replace the Irijule stuff.

The result was overwhelming!
The sensitivity was massively improved, the pressure spans a wider range than the original material.
So I converted both keypads to Velastat pads now and would like to share the way it has been done.

#### Update: 3M adhesive
While the mod as described was working nicely, I had a special issue with it. 
When modding I tend to open and close the Theoryboard multiple times.
Since the key pads are made from silicone, the adhesive tape I used to fix the Velostat on it is not sticking strongly, rather like a Post-It&trade; note.
Therefore the Velostat bit came off sometimes.

I found a special 3M double adhesive tape to get around that issue.
It unfortunately ius rather expensive but nicely does its job.
The "3M mod update" was added at the end of the page.

```diff
- Note: the sensitivity curve of Velostat makes it tricky to play with velocity and aftertouch.  One can adjust to it, but the planned sensitivity  control in FredBoard will make it easier!
```

The mod is easily reversible!

### Bill of Materials
- A **sheet of Velostat**. The material is also known as Linqstat (from another manufacturer). The Net has sources; [Adafruit are selling it for about 5$ per sheet](https://www.adafruit.com/product/1361), the size is sufficient for modding 3 or 4 boards easily.
- **Carpet tape**. Get a roll of the thinnest double sided tape you can get. Your local hardware shop will have a variety.
- **Textile duct tape**. I used 19mm wide tape from Tesa, but other brands will do. 
- **Some tools**: scalpel, tweezers, scissors, ruler.
- a **plectrum** to open the TB case.
- a **7mm square hand punch tool**. These are sold cheaply in sets from China - see Aliexpress or Amazon for it. 

Optional:
- a **cutting machine** to cleanly cut the 96 sensor pieces.
- a **heat gun** or **reflow workstation** to form the sensors.

### Disassembly
#### Opening the TheoryBoard
Put your TB on a flat surface where it is completely supported.
Turn it upside down.
Remove the 4 screws at the four corners.
Turn around the board, safely store the screws for later reassembly.
With a thin plectrum or other plastic tool to open smartphones or tablets carefully slide along the slit between upper and lower part of the case to release the 10+ plastic clamps.
**Apply the least force possible, the clamps are likely to break!**
Lift off the upper case and safely place it upside down on a flat surface somewhere - it is fragile.

#### Removing the keypads
Remove the white silicone key mats. 
These have four tiny protruding bolts on the corners that go down into holes in the PCB.
Take care not to tear these off.
Now you will see the original sensor foil in place:

Original sensors

The red arrows are pointing to the spots where the sensor foil is glued to the PCB.
These glue blobs have to be cut to separate foil and PCB. 
The easiest is to slide a razor or scalpel carefully between both to cut away the glue.

Glue spot

*Note:* To revert the mod you will have to glue the sensor foil in exactly the same position.

Lift off the foil, put it in a sleeve and store it safely, lying flat for a potential later reversion of the mod.

Original sensor foil removed

Now you will see the PCB sensors and center LEDs.
Take care not to scratch or soil the golden sensor surfaces.

PCB sensors

### Making the sensors
#### Preparing the Velostat
The Velostat material needs to be attached to the silicone key mat, one piece for each key.
The pieces must have a hole in the middle to let pass the LED's light.

The key structure in the silicone is hollow in the middle and slightly domed to the sides.
The most important area for the keys to work properly is the rim around the LED hole.
Contact to the sensors is made with this rim first, gradually widening the contact area when pressing a key.

Hence the exactness of the rim is relevant for the function of the keys, the outer area is less critical.

We will cut out squares of Velostat that have a square center hole matching that of the key and are some mm wide to each side.

Since Velostat itself is not adhesive, we need to add the carpet tape to it first.
Cut a length of carpet tape and laminate it as flat as possible to the Velostat sheet - lining up to one edge.
If you got some bubbles left between tape and Velostat, you may try to prick into it with a needle  and try to flat out the bubble.
Be careful: once stuck, the Velostat is no more removable from the tape.

With a scalpel and a ruler or a scissor cut the laminated piece of Velostat/tape from the sheet to get a stripe.

Laminated with tape

Cut stripe

#### Cutting the sensor pieces
We will need 96 pieces from our laminated material.
I used these dimensions (note again that the inner 7mm is mandatory!):

Cut dimensions

I have no cutting machine available, so I cut all the pieces by hand.
First I cut 17mm x 17mm squares with a ruler and a scalpel, as precise as I could manage. 
You will see below that I did not well, but the outer border is less relevant.

17mm alignment with ruler

Next I punched out the 7x7mm holes with a hand punch tool and a hammer.
Again I sometimes missed the center a bit, the hole was shifted to the sides by up to 1mm.
Does not matter too much as well...

Square punch tools

I used these punch tools. 
The larger one is a 17x17mm square, but I found it easier to cut the squares by hand than punching those out.

#### Applying the material
Now we will peel off the liner paper from the cut out pieces and place on on each key on the silicone mat.
Be sure to align the inner hole as good as possible with the punched hole of the Velostat piece.

The material will not fit perfectly to the keys due to their domed shape.

Piece placed

Now we have two options to get the material in a better adjusted shape:
- When the board is reassembled, for some time firmly press on each key before using the board. This will bend the material over time to accept the form of the keys. I did this with one side of my board and never was urged to correct anything since.
- Use a heat gun or reflow workstation with moderate temperature (135°C is more than sufficient) to soften the material, then gently nudge it into the right shape. **Be careful not to heat the material too much - Velostat does shrink when heated!**

The heat formed piece will look like this:

Piece heated

You can see the white carpet tape shine through now where the Velostat has shrunk a little, but the form is exactly molded to the key shape.

Repeat this for all 96 pieces on both silicone mats.

All in place

As you can see, I was not very successful cutting exactle fitting square pieces, but that does not matter at all!

### Adding the bumpers
If used as is, our keypad would work already, but it will generate a lot of unwanted key presses due to the Velostat lying on the sensor surface already and being highly conductive.
So we need to separate it from the sensors by just a little bit.
For that purpose we will apply small bumper plates made from duct tape.

I cut the textile duct tape to small squares of 5x5mm.
These squares are placed on the intersections of the stripes separating the golden sensor surfaces, tilted by 45°.

Single bumper

Repeat that for all intersections and add some more bumper pieces to the outer separations as well.
Leave out the 4 corners as there the silicone bolts must snap into the PCB.
Seen in green here (I ran out of black duct tape :grinning:)

All bumpers

### Reassembly
Put the silicone mats back on the PCB.
Be sure to slide the 4 bolts on the corners into their fixing holes in the PCB.

Now you can do a first test already to see if everything is working.
Plug in your board into your PC and boot it up.
Try out each single key to see if it is working and no other keys are triggered with it.

The pieces of Velostat can be removed easily - if you find a defective one just try with a new one.

If you found everything working, get the upper case and set it back in place.
Remember the fragility of the clamps and use no force to seize it in.
If it is snapped on, turn the board and fasten the 4 corner screws.

#### Mod the Mod
Alain Blanchard had an idea that may be worthwhile considering: to improve the feel of the keys, put some soft silicone under them.
I had some 1mm self-adhesive foamed rubber lying around, so I stamped out 6mm circles and placed these on the duct tape bumpers.
I did not remove the duct tape because I was afraid the glue on the rubber would not be easily removable in case.

This is the result:

Soft pads

### 3M tape mod
There is a special 3M double adhesive tape (type 9731) that has one side with a traditional acrylic glue, but the other coated with a special silicone glue.
This tape will stick very good to both the Velostat and the silicone key pads. It is expensive, though: I had to buy a 65m roll of 14mm wide tape for 60+€, knowing I would need only 1.5m in the end. It was worth it for me, you may have to decide yourself.

The tape has two liners, a brownish paper one on the acrylic side, a transparent plastic liner on the silicone side.

3M tape

#### Additional tools used
To make the production of the almost 100 Velostat tiles easier I created some 3D printed tools:

Making tools

From the left, the grey part is called the "Press" and is used to exactly center a tile on a keypad key. 
The green part ("Cut") is to cut a tile to measure from a stripe of Velostst sandwich and the yellow ("Punch") is used to adjust the length for a commecrial punching tool.

The STL files can be found here and are named "StanzlehreRund-Press.stl", "StanzlehreRund-Cut.stl" and "StanzlehreRund-Punch.stl", respectively.

I used this [this 8mm punch from Amazon](https://amzn.eu/d/eW3AJuU), the Punch adjustment part is constructed for it.
You may have to modify it if your punch is different.
The purpose is to have the 8mm hole centered 7mm before the end of the Velostat stripe, so that it will be in the center of a 14mm x 14mm square tile.

#### Making the tiles
The steps are similar to those above, but modified to use the printed tools.
In the end the making of 100 tiles took less than half of the time than I used originally.

1. pull off the brown paper liner from a length of 3M tape and apply it to the Velostat.
Try to avoid any bubbles of air between the materials.

2. cut the stripe from the Velostat sheet, resulting in a 14mm wide sandwich from 3M tape and Velostat. 
The cleaner you will cut, the easier the further processing will be.

3. cut one end of the stripe to be exactly right-angled. 
Push it into the punch tool with the printed guide inserted.
Punching holes

4. insert the punched stripe into the cutting tool and cut it at the marked line to get a 14mm x 14mm square tile.
Cut tile

5. repeat... :wink:

#### Placing the tiles
Peel off the transparent plastic liner from a cut tile and place the tile on the "Press" tool, adhesive side up.

Place tile on Press tool

Now insert the Press tool's rod into the hole of a key.
It will follow the rectangular form and hence center the tile over the key.

Press tool set in

Firmly press the tool down to fix the tile on the key.
You may wiggle the tool a bit to all sides to better follow the domed form of the key.
Remove the tool to find the tile stuck in place.

Tile in place

#### Result
The result has all tiles at their positions, firmly sticking to the silicone.

All tiles set

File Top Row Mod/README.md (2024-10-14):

## The Top Row Mod
The choice of colors, font and haptics for the top row buttons (sensors in fact) of the original Irijule design was not optimal as far as I am concerned.
I hardly could read the buttons, especially in darker environments and the cavities were too deep to please me.
So it is time for another mod.

### This mod requires some making skills - you have been warned!
To replace the top row buttons we will need to remove the old panels, print new buttons from TPU on a 3D printer at least.
The planned lighting add-on additionally requires some soldering.

### Bill of materials
We will need:
- a **plastic spatula** to lift off the original panels
- a **hot air** gun or reflow workstation is helpful
- a **3D printer**, ideally an **IDEX** one that is able to print two filaments at a time.
- two contrasting colors of **TPU filament**. 

### Disassembly
First open the case by removing the 4 screws from the bottom side.
Lift off the lid **carefully** by sliding a plastic plectrum or spatula along the long sides of the lid and unhooking the plastic clamps that are holding the lid.

Put the lid aside, laying it flat on its face.
It is fragile, so take care.

The printed panels are glued to the PCB with a double-side adhesive tape.
With hot air (I had 135°C with good results) warm up the panels over the sensor plates.
If you do it slowly and step by step, you will be able to push the spatula between the panel and the PCB.
Gently push the spatula inside, lifting the panel.
If it is too hard to push, rather warm up some more instead of forcing the spatula in.

If you succeeded removing the plates and adhesives you will see the sensor plates:
Sensor plates

### Printing the buttons
The buttons will be printed from TPU filament.
TPU is not the easiest stuff to print, known for its "stringing" tendency that will pull out thin threads of filament when the extruder is moving.
You should know which settings are best for your choice of filament.
The TPU is profiting enormously from being dried, so if you own a filament dryer, use it!

I did not try to use other filaments like PLA or PETG.
Those may work as well, but the button dimensions (``buttonWidth`` in ste OpenSCAD file) may need to be adjusted for it.
The fitting of the buttons is as tight as can be.

The STL files for the buttons with the standard letters as were on the original plates are to be found <a href="https://github.com/Miq1/FredBoard/tree/main/Top%20Row%20Mod/Basic%20buttons%20STL"> in the 'Basic Buttons STL' directory</a>

There are sets of two STLs for each button stripe:
- **C-F**, Letters and Buttons - the left half of the left button row
- **F#-B**, Letters and Buttons - the right half of the left button row
- **5-12**, Letters and Buttons - the two left buttons of the right button row
- **M1-M7**, Letters and Buttons - the middle Mode buttons of the right button row
- **U1-U3**, Letters and Buttons - the right User buttons of the right button row

The 'Letters' files are containing the inlay letters, the 'Button' files the button stripe.
I chose a separation in the listed segments to allow for different color letters on the right hand side and to keep the size of the printed objects small to fit on smaller print beds.

See below how to use both.

#### Ideal: IDEX printer with 2 TPUs
An IDEX 3D printer is able to print two filaments with two extruders simultaneously.
This is perfect for our buttons to lay in the letters in a different color.
Any other printer able to print more than one filament at a time will be fine, too.

I will describe the procedure for Prusaslicer here - that is the one I am using.
Other slicers will do as well, but you may need to adjust the settings accordingly.

To print a strip you will need to open the Letters and Buttons files of that strip simultaneously.
Load two STL files

If you do, Prusaslicer will ask you if to combine both STLs into one compound:
Combine into compound

Answer 'YES' to that.
Now the object will be placed on the bed facing up.
On the right hand side, check if the extruders have been assigned correctly to the buttons and letters. 
If not, adjust it now.
Select colors

To get a cleaner look, it is better to print the top surface of the buttoms placed on the print bed, so we need to flip the print object over now.
Select the object and in the tool bar on the left select the rotate tool.
Rotate object

Grab the red or green handle and turn the object by exactly 180°.
If you will move the mouse pointer to the inner circle of the rotate tool while holding down the left mouse key, you will be able to rotate in 45° steps.

Next use the tool below the rotate tool in the tool bar to place it on the print bed.

Since we have two TPU filaments in use, we will have to print support structures with these as well.
TPU is sticking on TPU like hell, so we need sensible settings to prevent the supports coming out unseparatable from the button strip.
These are the settings I found to allow an "easy" (well, sort of :wink:) removal of the supports:
Support print options

#### Alternative: single TPU and manual coloring
For those not having access to an IDEX printer there is an alternative way to get colored buttons.
The result will depend on your skills, but will be functional in any case.

You will need in addition to the above:
- **acrylic paint** in a color you are preferring
- a **syringe and tip** or small **brush**
- differntly grained **sand paper**

First print the Buttons file only for the strip you like to do without the Letters file on your printer with a single TPU color.
There will be cavities in it where the letters are supposed to sit.
raw buttons print
Acrylic paint

Now take a syringe and fill it with the acrylic paint (or use a brush with it) and let the paint flow into the letter grooves.
Be sure to completely fill these without spilling too much on the outside.
Letters filled

Let it dry **thoroughly!**
I set it aside overnight to be sure it had dried completely.

Finally sand the buttons with papers in increasing granularity to remove the excess paint and get a smooth surface on the buttons. 
Expect to not be able to remove every single stain of paint.
The paint will diffuse into tiny slits in the 3D print.
You will have to live with it, unfortunately.
I am not that skilled, so my result may not be the most convincing:
Finished set

### Assembly
The buttons are pushed into the square holes of the lid from the inside.
Please be careful not to break the lid, as the buttons will sit really tight in the holes.
Push them until the button surfaces are flush with the outside of the lid and the buttons' back plate touches the inner square frames around the holes.
Buttons set in

After the buttons are all set, you can replace the lid and fasten the screws from the bottom side of the board.

### Modifying the buttons
The Letters and Buttons STL files all were generated by the OpenSCAD design in ``BasicButtons.scad``.
The relevant options to be modified all are in the first section of that file:
```
// Unilluminated upper row buttons on FredBoard

fontSize = 7;           // size of text
textXOffset = 2;        // Distance to move text right/left in non-center mode
textYOffset = 4;        // Distance to move text up
fontName = "DejaVu Sans Condensed";

// Text strings
textLeft = ["C", "C#", "D", "D#", "E", "F", "F#", "G", "G#", "A", "A#", "B"];
textLeftAlt = ["C", "Db", "D", "Eb", "E", "F", "Gb", "G", "Ab", "A", "Bb", "B"];
textRight = [ "5", "12", "M1", "M2", "M3", "M4", "M5", "M6", "M7", "U1", "U2", "U3"];
textRightAlt = [ "5", "12", "Io", "Do", "Ph", "Ly", "Mx", "Ae", "Lo", "U1", "U2", "U3"];

// 1. Make the button base 
// Use the text strings from above to generate a full set or use
// makeButtons(["one", "two", "foo", bar"]) notation to generate your own.
//
// The text vector is mandatory, optional is
//   center = true/false to center the text on a button

// makeButtons(textLeft, center=true);

 // 2. Make the letters
 // Same options as above
 // *** Be sure to use the very same options as for the makeButtons() call,
 // *** else the result will be defective!
 
// makeLetters(textLeft, center=true);

// Both must be rendered separately and exported as separate STL!
do = 1;
centerT = true;
// textString = slice(textLeft, 0, 5);   // Left half of left row
// textString = slice(textLeft, 6, 11);  // Right half of left row
// textString = slice(textRight, 0, 1);  // 5, 12
textString = slice(textRightAlt, 2, 8);  // M1-M7
// textString = slice(textRight, 9, 11); // U1-U3

if(do==1) {
  makeButtons(textString, centerT);
} else {
  makeLetters(textString, centerT);
}
```

This was written for OpenSCAD, a free parametric CAD application available for several operating systems.
OpenSCAD has a nice IDE to develop these designs, you immediately will see your changes on the screen to check.
You will need a more recent nightly version of OpenSCAD to run the design, because the ``textmetrics`` addition was added after the last official version was published (2021).
This function is used to enable the centering of text on a button.

You are not bound to the given texts at all.
with a call like ``makeButtons(["I", "am", "FB"])`` and ``makeLetters(["I", "am", "FB"])`` respectively you can put any text on the buttons you like. 

With the ``Run`` command you will execute your design to see the results (leftmost icon on the screenshot below).
Once you are satisfied use the ``Render`` command to refine the object to be exported (next icon to the right of ``Run``).
Finally use the ``F7`` key to export the rendered object to a STL file.

OpenSCAD commands

You **absolutely must** run the design twice, one time with the ``makeButtons()`` call enabled, another with ``makeLetters()`` with **exactly the same parameters** to get a set of matching Butttons and Letters STL files.

I did an alternative set for the mode buttons, to be found in the ``M1-M7_Alt....stl`` files:
Alternate Mode keys

### The Result
This is my current design - the blue TPU for the Mode keys is a bit too light to be optimal, but that was the only I had in stock.
The Result
The Result

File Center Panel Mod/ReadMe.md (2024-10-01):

## The Center Panel Mod
I always disliked the lack of haptic response from the center panel sensors and found the printed symbols too dark.
With FredBoard the lower buttons are getting new and diverse functions anyway, so the original print has no more meaning mostly.
So I decided to build a new center panel...

### A word on the sensors
The sensors are given as are, despite their shortcomings in some aspects.
Fred is struggling to get around some, but the basic principles will remain the same.

The sensors are based on Infineon Capsense :tm: chips.
These are watching the capacitive changes around 4 sensors per chip.

- the sensors are no buttons or switches, so anything possible with a proper switch (double click, holding etc.) will not work
- the chips will constantly try to adapt to the capacitive environment around the sensors. This can lead to sensors not always reacting
- if one chip is struggling, all sensors attached to that chip will be unresponsive simultaneously
- besides the 19 sensors on the center panel the 2 * 12 sensors in the top row are the same type
- the chips seem to go into a 'sleep mode' after some time. They are woken again by another sensor contact, but that will not be sent as a button press at all times. You may have to push a second time to activate it

The Result

### Bill of materials
First you will need some tools:

- gaffer tape
- a plectrum to open the TB case
- scalpel or razor blade
- a ~2.5mm drill
- a 3D printer - ideally able to print both TPU and PETG or PLA
- a soldering iron to melt in the threads

Plus some parts and consumables:

- translucent or white TPU filament
- opaque PETG or PLA filament
- a few drops of silicone adhesive (if you want to fix the color display filter)
- 4 M2 melt-in threads
- 4 M2 x 15mm screws with countersunk heads
- screen protector or color foil

### Disassembly
This will require some patience and carefulness to not damage anything you may want to put back later...

#### Open the case
Take off the top case lid by removing the four screws from the bottom side corners and *carefully* unkhooking the plastic clamps that are holding the lid on the inside. 
This can be done by sliding the plectrum all along the slit between lid and bottom case and carefully loosening the clamps one by one.

#### Remove the screen cover
Now we need to remove the printed screen cover from the center panel.
It is glued to the panel proper with a tough glue pasted on the complete surface, leaving out the display only.

Screen on

The best way I found is to start at a corner and slide a scalpel or razor blade flatly between printed screen and panel.
As soon as you can lift the edge a bit, do so and keep it under tension.
Now proceed with the blade along the edges and deeper into the opening.
Be careful to keep the blade flat to not damage the screen or panel.
Take special care of the flat display flex cable at the top edge.

A gentle stream of hot air may help, but take care to not overheat the materials.

This will take some time!

With this procedure some of the white inserts may already come from the panel. 
This is just fine, we will need to remove them in any case.

Screen off

Now use pieces of gaffer tape to dab off the glue residues.
If you repeatedly will press the tape on the glue and quickly lift it off again, the glue will rather stick to the tape than to the panel.

With the same technique you will be able to pull out all the 19 white inserts as well.

All removed

#### Lift off the center panel
Now 4 screws are accessible at the corners of the panel.
These are self-cutting plastic screws that may work with the new center panel, but I definitely do not recommend that.
The more you will loosen and fasten these screws, the wider the thread will get - finally not able to hold the screw any more.

I do recomment replacing these screws by a set of proper metric threads and screws.

1. remove the 4 screws
2. gently lift the center panel at one end - not too far! Be sure to keep the flex cables on the bottom side unharmed. The top side needs to be slid down a bit to let the USB and power sockets glide out of the case holes
3. with a hand drill slightly widen the screw holes in the bottom part of the case
4. use a heated soldering iron to set the melt-in threads into these holes. Do not force or overheat it
5. repeat at the other end of the panel to have all four threads replaced.

Melt-in set

### The new panel
The panel consists of two different components - the screen plate made from PETG or PLA, and the 19 button insets made from TPU.
You will find the STL files to print the parts right here in the files list.

Screen plate CAD

The screen plate (here seen from below) is made to slip in the four former screw cutouts at the panel's corners, thus lying flat on the panel.
The display opening has a frame around it to hold an optional color filter or screen protector and openings for the 19 buttons.

Buttons CAD

The buttons will be needed multiply, with the exception of the oval middle menu button.
- arrow left: 2 items
- arrow up: 2 items
- oval center button: 1 item
- rhombic select button: 14 items.

These buttons will be set into the respective openings in the panel, replacing the removed white original parts.

Plate PETG
Buttons TPU

### Assembly
Insert all 19 printed TPU buttons into their holes in the panel. 
You may need to cut or sand off remaining strings from the prints to have them fit exactly into the openings.

Buttons set in

If you would like to add a colour filter, cut a 43mm x 78mm piece from the filter material, it will fit exactly into the frame around the display opening.
Fix it with a few drops of silicone adhesive - to keep it in place while have it removable again.

Colour filters

Now place the screen plate over all buttons and gently slide it into place.
The buttons should go easily through their holes, the 4 corner squares must fit into the cutouts of the panel.

Finally fasten the screen plate with the M2 screws into the melted-in threads at the four corners.

Plate set

Close the lid, fasten the screws from the bottom side. 

Enjoy! :wink:

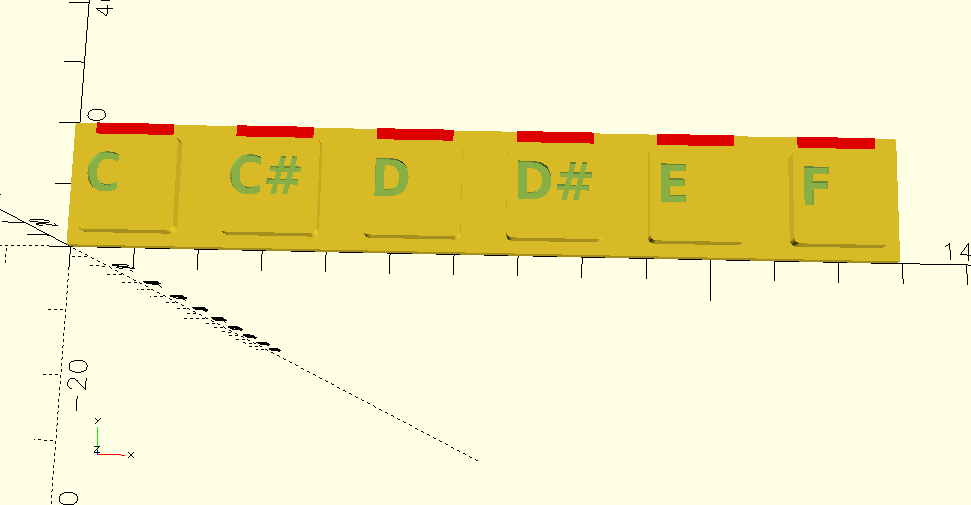
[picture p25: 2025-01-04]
LED-Buttons Mod/Pictures/ButtonsLit.png

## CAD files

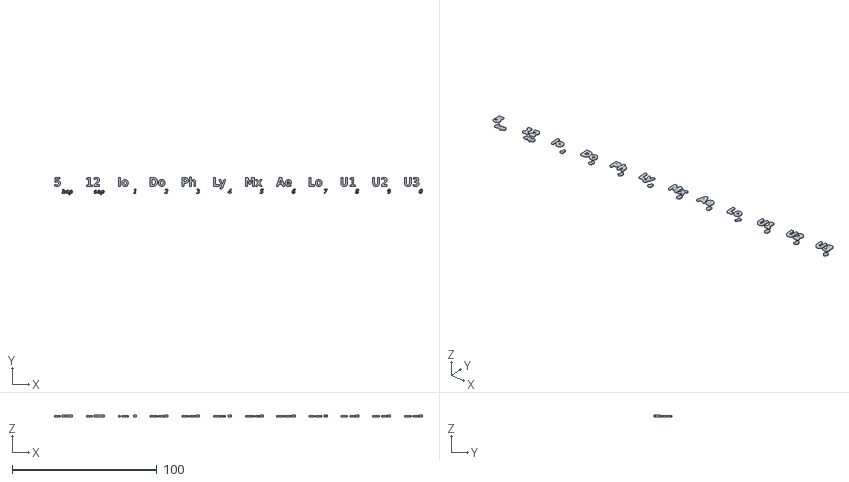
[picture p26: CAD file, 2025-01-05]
LED-Buttons Mod/3D STLs/LettersLitFullRightIo_Do2nd.stl
254.6 x 12.2 x 1.10

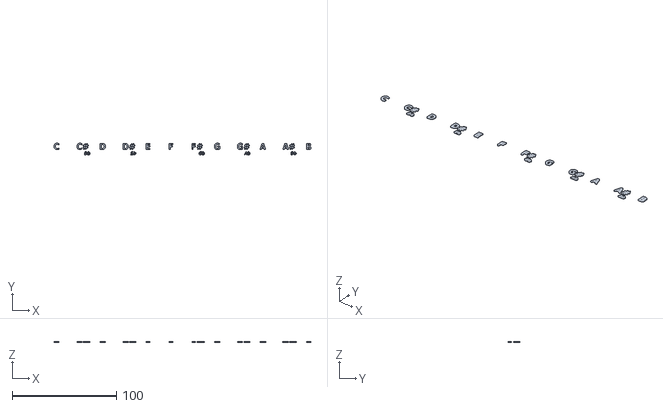
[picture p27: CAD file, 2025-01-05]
LED-Buttons Mod/3D STLs/LettersLitFullLeft2nd.stl
246.8 x 11.2 x 1.10

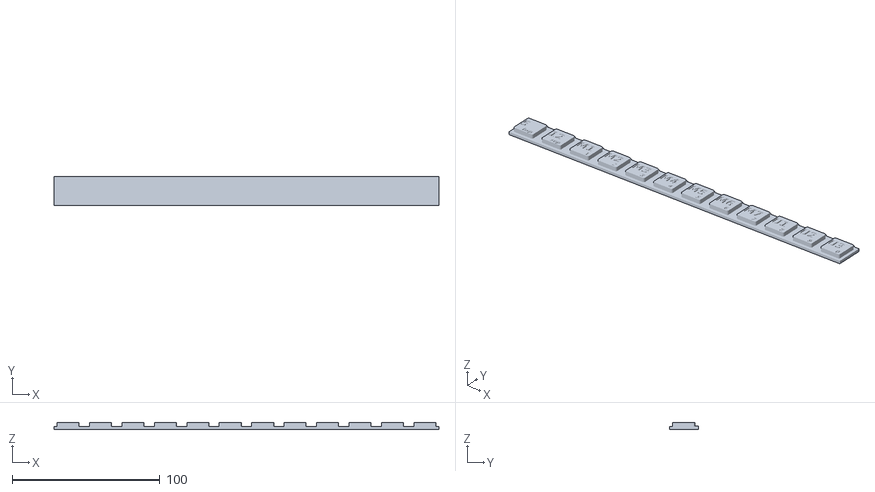
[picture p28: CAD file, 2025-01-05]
LED-Buttons Mod/3D STLs/ButtonsLitFullRightM1_M72nd.stl
261.0 x 19.4 x 5.00

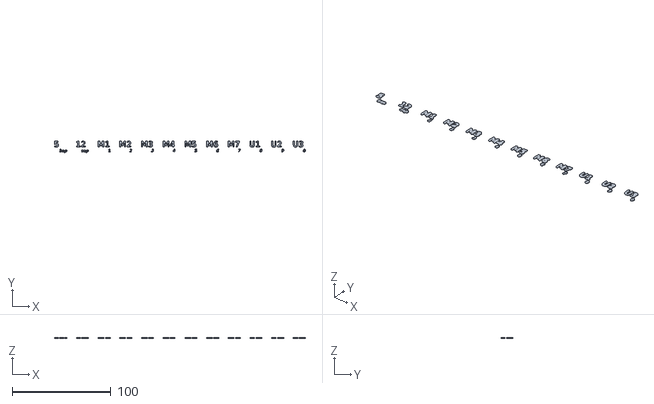
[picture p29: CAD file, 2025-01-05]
LED-Buttons Mod/3D STLs/LettersLitFullRightM1_M72nd.stl
254.6 x 12.1 x 1.10

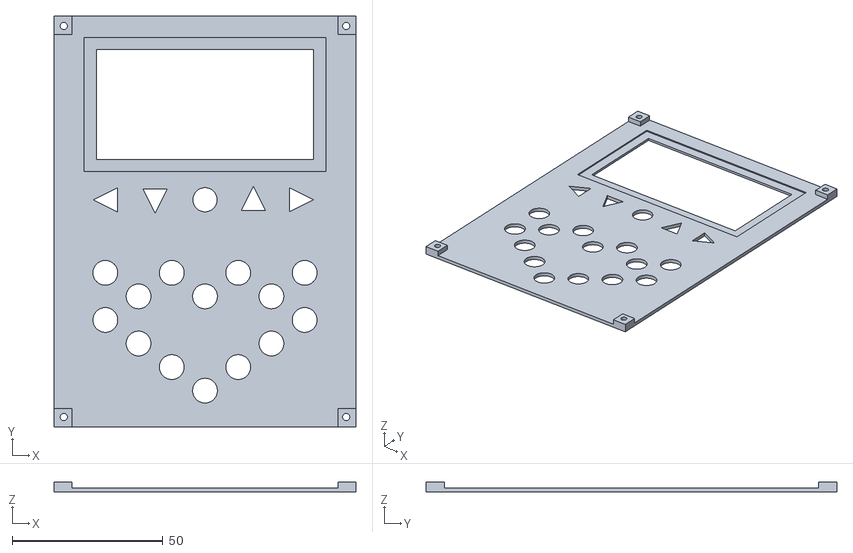
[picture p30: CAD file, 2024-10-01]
Center Panel Mod/TB-Parts-Plate.stl
100.0 x 136.0 x 3.40

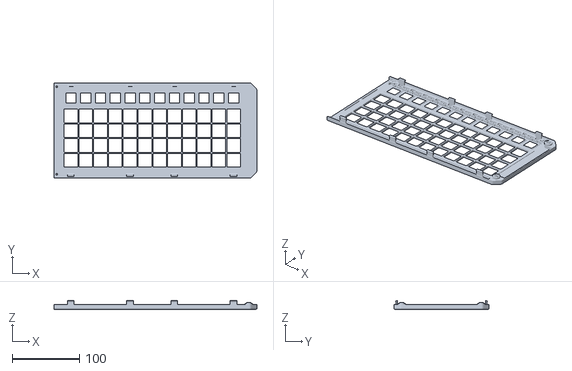
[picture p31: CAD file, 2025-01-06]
LED-Buttons Mod/3D STLs/TBLid-LeftKB.stl
302.0 x 142.0 x 13.0

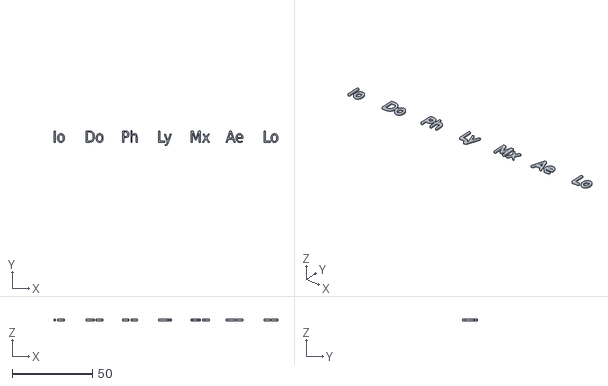
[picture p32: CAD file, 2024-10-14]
Top Row Mod/Basic buttons STL/M1-M7_AltLetters_basic.stl
139.7 x 9.41 x 1.00

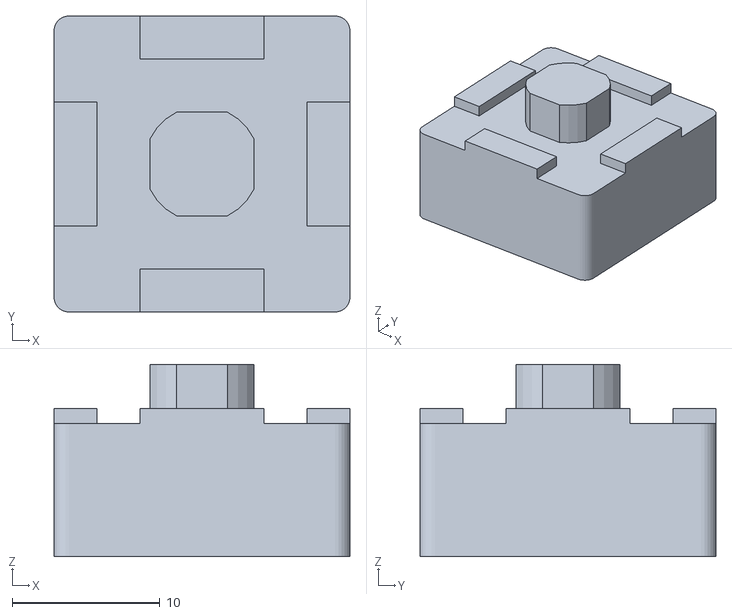
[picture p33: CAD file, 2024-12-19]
Velostat-Mod/StanzlehreRund-Press.stl
20.0 x 20.0 x 13.0

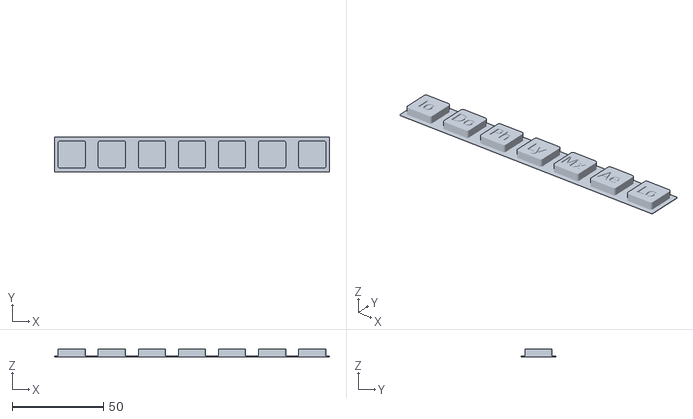
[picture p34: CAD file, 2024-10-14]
Top Row Mod/Basic buttons STL/M1-M7_AltButtons_basic.stl
151.0 x 19.0 x 4.42

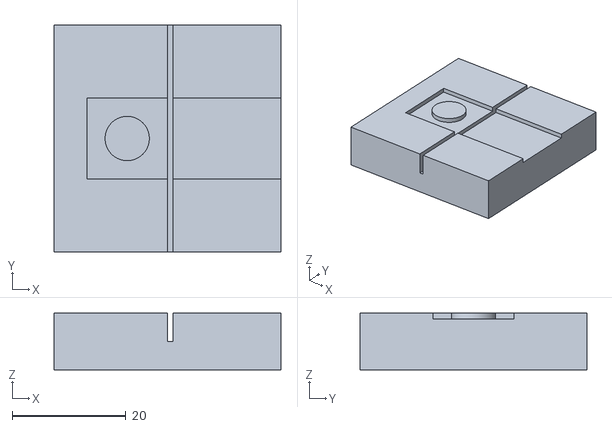
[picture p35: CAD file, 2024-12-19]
Velostat-Mod/StanzlehreRund-Cut.stl
40.0 x 40.0 x 10.0

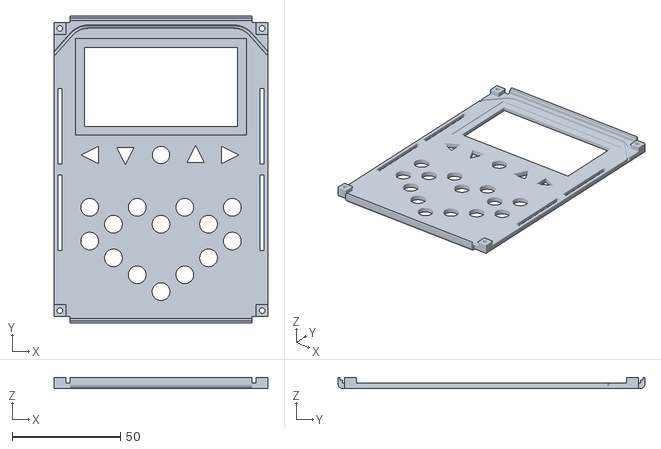
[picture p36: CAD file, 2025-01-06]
LED-Buttons Mod/3D STLs/TBLid-Plate.stl
99.0 x 142.0 x 5.00

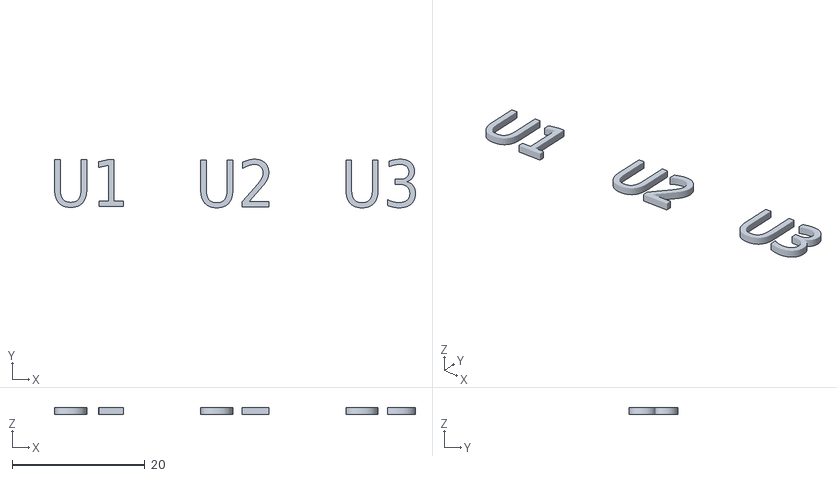
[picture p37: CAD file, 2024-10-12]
Top Row Mod/Basic buttons STL/U1-U3_Letters_basic.stl
54.5 x 7.35 x 1.00

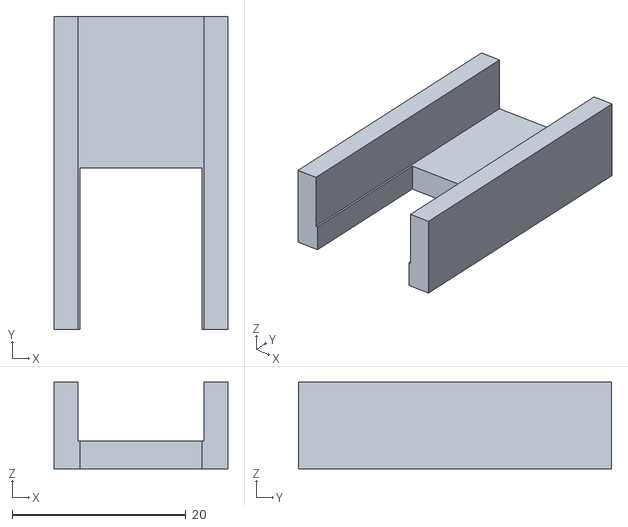
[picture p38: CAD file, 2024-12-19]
Velostat-Mod/StanzlehreRund-Punch.stl
20.0 x 36.0 x 10.0

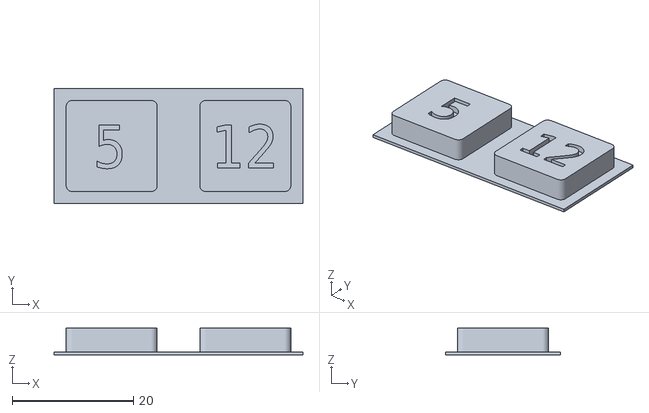
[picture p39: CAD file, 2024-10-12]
Top Row Mod/Basic buttons STL/5-12_Buttons_basic.stl
41.0 x 19.0 x 4.42

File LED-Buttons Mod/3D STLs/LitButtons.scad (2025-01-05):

// Upper row buttons on FredBoard

// Customizer variables
/* {Global] */
// What to render
do = 0; // [0:Letters, 1:Buttons]

// Item to render
item = 1; // [0:C to F, 1:F# to B, 2:5/12, 3:M1 to M7, 4:Io to Lo, 5:U1/U2/U3, 6:Full left set, 7:Full right set, 8:Full alternate right set]

// Centered text?
centerT = false;

// Lit buttons?
lightT = true;

// Second text line?
secondText = true;

/* [Hidden] */

fontSize = secondText == true ? 6 : 7;           // size of text
textXOffset = 0;        // Distance to move text right/left in non-center mode
textYOffset = secondText == true ? 6 : 4;        // Distance to move text up
fontName = "DejaVu Sans:style=Condensed Bold";

fontSize2 = 3;          // size of second text
textXOffset2 = 13;      // horizontal offset of 2nd text
textYOffset2 = 1;       // vertical offset of 2nd text
fontName2 = "DejaVu Sans:style=Condensed Bold Oblique";

// Standard text string vectors - 12 button texts from left to right in each
textLeft = ["C", "C#", "D", "D#", "E", "F", "F#", "G", "G#", "A", "A#", "B"];
textLeftAlt = ["C", "Db", "D", "Eb", "E", "F", "Gb", "G", "Ab", "A", "Bb", "B"];
textLeft2nd = [" ", "Db", " ", "Eb", " ", " ", "Gb", " ", "Ab", " ", "Bb", " "];
textRight = [ "5", "12", "M1", "M2", "M3", "M4", "M5", "M6", "M7", "U1", "U2", "U3"];
textRightAlt = [ "5", "12", "Io", "Do", "Ph", "Ly", "Mx", "Ae", "Lo", "U1", "U2", "U3"];
textRight2nd = [ "bsp", "sep", "1", "2", "3", "4", "5", "6", "7", "8", "9", "0"];

// -----------------------------------------------------------------
// All below is internal - do not change!
// -----------------------------------------------------------------
iVector = [slice(textLeft, 0, 5), slice(textLeft, 6, 11), slice(textRight, 0, 1), slice(textRight, 2, 8), slice(textRightAlt, 2, 8), slice(textRight, 9, 11), textLeft, textRight, textRightAlt];
iVector2 = secondText == true ? [slice(textLeft2nd, 0, 5), slice(textLeft2nd, 6, 11), slice(textRight2nd, 0, 1), slice(textRight2nd, 2, 8), slice(textRight2nd, 2, 8), slice(textRight2nd, 9, 11), textLeft2nd, textRight2nd, textRight2nd] : [];
iOption = ["C_F", "F#_B", "5_12", "M1_M7", "Io_Do", "U123", "FullLeft", "FullRightM1_M7", "FullRightIo_Do"];

textString = iVector[item];
textString2 = iVector2[item];
fileName = concat(do == 0 ? "Letters" : "Buttons", lightT == true ? "Lit" : "Plain", iOption[item], secondText == true ? "2nd" : "", ".stl");

echo("Export file name: ", join(fileName));

if(do==1) {
  render() makeButtons(textString, textString2, centerT, lightT);
} else {
  render() makeLetters(textString, textString2, centerT, lightT);
}

buttonWidth = 15;       // width/depth of a button
buttonHeight = 3;       // height of a button
buttonGap = 7;          // distance between buttons
buttonFrame = 2;        // outer rim around buttons
roundRadius = 1;        // corner rounding radius
$fn = 40;               // rendering steps
frameHeight = 2;        // adjust panel height
lightWidth = 0.4;       // additional rim for LED mounts
lightCubeWidth = 12;    // width of the extruded light guiding cube
lightTunnel = 1.1;      // radius of the light guiding tunnels
lightDistance = 9.2;    // narrow distance between LEDs
lightHeight = 1.1;      // elevation of light tunnels
tilt = 5;               // angle to tilt the light tunnels towards the center

function slice(list, start, end) = [for (i = [start:end]) list[i]];

join = function (l,delimiter="") 
  let(s = len(l), d = delimiter,
      jb = function (b,e) let(s = e-b, m = floor(b+s/2)) // join binary
        s > 2 ? str(jb(b,m), jb(m,e)) : s == 2 ? str(l[b],l[b+1]) : l[b],
      jd = function (b,e) let(s = e-b, m = floor(b+s/2))  // join delimiter
        s > 2 ? str(jd(b,m), d, jd(m,e)) : s == 2 ? str(l[b],d,l[b+1]) : l[b])
  s > 0 ? (d=="" ? jb(0,s) : jd(0,s)) : "";

  module basePlate (buttons, light = false) {
  cube([2*buttonFrame+buttons*buttonWidth+(buttons-1)*buttonGap, 2*buttonFrame+buttonWidth + (light == true ? lightWidth : 0), frameHeight]);
}

module singleButton (textIs = "new", textIs2 = "", center = false, centerShift = 0, light = false) {
  tw = textmetrics(textIs, fontSize, fontName);
  tw2 = textmetrics(textIs2, fontSize2, fontName2);
  union() {
    difference(){
      // base form is a rounded square
      linear_extrude(height=buttonHeight)
        offset(r=+roundRadius)
        offset(delta = -roundRadius) 
        square(size = [buttonWidth, buttonWidth]);
      // ...minus the text 
      translate(center == true ? [buttonWidth/2-tw.size.x/2-centerShift, textYOffset, buttonHeight-1] : [textXOffset, textYOffset, buttonHeight-1])
        linear_extrude(1.1)
        text(textIs, size = fontSize, font = fontName);
      // ...and second text, if present
      if(textIs2!="") {
        translate([textXOffset2-tw2.size.x, textYOffset2, buttonHeight-1])
          linear_extrude(1.1)
          text(textIs2, size = fontSize2, font = fontName2);
      }
    }
    if (light == true) {
      translate([buttonWidth/2-lightCubeWidth/2, buttonWidth, 0])
        color("Red")
        cube([lightCubeWidth, buttonFrame + lightWidth, 0.6 ]); 
    }
  }
}

module makeButtons(bv = ["new"], bv2 = [], center = false, light = false) {
  buttons = len(bv);
  centerShift = 1;
  difference() {
    union() {
      basePlate(buttons, light);
      for (i = [0 : buttons - 1]) {
        tw = textmetrics(bv[i], fontSize, fontName);
        translate([buttonFrame+i*(buttonWidth+buttonGap), buttonFrame, frameHeight])
          singleButton(bv[i], bv2[i], center, centerShift, light);
      }
    }
    if (light == true) {
      for (i = [0 : buttons - 1]) {
        translate([buttonFrame+i*(buttonWidth+buttonGap), buttonFrame, lightHeight ]) {
          translate([buttonWidth/2-lightDistance/2, buttonWidth+buttonFrame+2, 0])
            rotate([-90+tilt, 0, 180+tilt])
            cylinder(r = lightTunnel, h = buttonWidth); 
          translate([buttonWidth/2+lightDistance/2, buttonWidth+buttonFrame+2, 0])
            rotate([-90+tilt, 0, 180-tilt])
            cylinder(r = lightTunnel, h = buttonWidth); 
          translate([buttonWidth/2-lightDistance/2, buttonWidth/3, 0.8])
            rotate([-90, 0, -90])
            cylinder(r = lightTunnel, h = lightDistance); 
        }
      }
    }
  }
}

module makeLetters(bv = ["new"], bv2 = [], center = false, light = false) {
  buttons = len(bv);
  centerShift = 1;
  for (i = [0 : buttons - 1]) {
    tw = textmetrics(bv[i], fontSize, fontName);
    tw2 = textmetrics(bv2[i], fontSize2, fontName2);
    translate([buttonFrame+i*(buttonWidth+buttonGap), buttonFrame, frameHeight]) {
      translate(center == true ? [buttonWidth/2-tw.size.x/2-centerShift, textYOffset, buttonHeight-1] : [textXOffset, textYOffset, buttonHeight-1])
        color("Green") 
        linear_extrude(1)
        text(bv[i], size = fontSize, font = fontName);
      // ...and second text, if present
      if(bv2[i]!="") {
        translate([textXOffset2-tw2.size.x, textYOffset2, buttonHeight-1])
          color("Blue")
          linear_extrude(1.1)
          text(bv2[i], size = fontSize2, font = fontName2);
      }
    }
  }
}

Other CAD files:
LED-Buttons Mod/3D STLs/ButtonsLitFullLeft2nd.stl
LED-Buttons Mod/3D STLs/ButtonsLitFullRightIo_Do2nd.stl
LED-Buttons Mod/3D STLs/TBLid-RightKB.stl
Top Row Mod/Basic buttons STL/F#-B_Letters_basic.stl
Top Row Mod/Basic buttons STL/BasicButtons.scad
LED-Buttons Mod/3D STLs/BendingTool.stl
LED-Buttons Mod/3D STLs/ButtonsLit5_122nd.stl
LED-Buttons Mod/3D STLs/ButtonsLitC_F2nd.stl
LED-Buttons Mod/3D STLs/ButtonsLitF#_B2nd.stl
LED-Buttons Mod/3D STLs/ButtonsLitIo_Do2nd.stl
LED-Buttons Mod/3D STLs/ButtonsLitM1_M72nd.stl
LED-Buttons Mod/3D STLs/ButtonsLitU1232nd.stl
LED-Buttons Mod/3D STLs/CableClamp.stl
LED-Buttons Mod/3D STLs/LettersLit5_122nd.stl
LED-Buttons Mod/3D STLs/LettersLitC_F2nd.stl
LED-Buttons Mod/3D STLs/LettersLitF#_B2nd.stl
LED-Buttons Mod/3D STLs/LettersLitIo_Do2nd.stl
LED-Buttons Mod/3D STLs/LettersLitM1_M72nd.stl
LED-Buttons Mod/3D STLs/LettersLitU1232nd.stl
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

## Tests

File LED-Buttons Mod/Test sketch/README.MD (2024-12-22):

### Prerequisites

You will need the FastLED library (compiled for the ESP8266)!

To build the test program I recommend using PlatformIO, but of course the Arduino-IDE will work.

The D6 pin must be connected with the DATA IN line of the LED stripe. The D5 ping will cycle through the test modes when pulled to GND shortly.

Test modes:

1. 2s all LEDs ON, a few set to a different color. Then 2s of OFF before repeating the cycle.

2. LEDs switched on in pairs, leaving two OFF in between

3. All LEDs blue with a yellow dot wandering through in sequence.

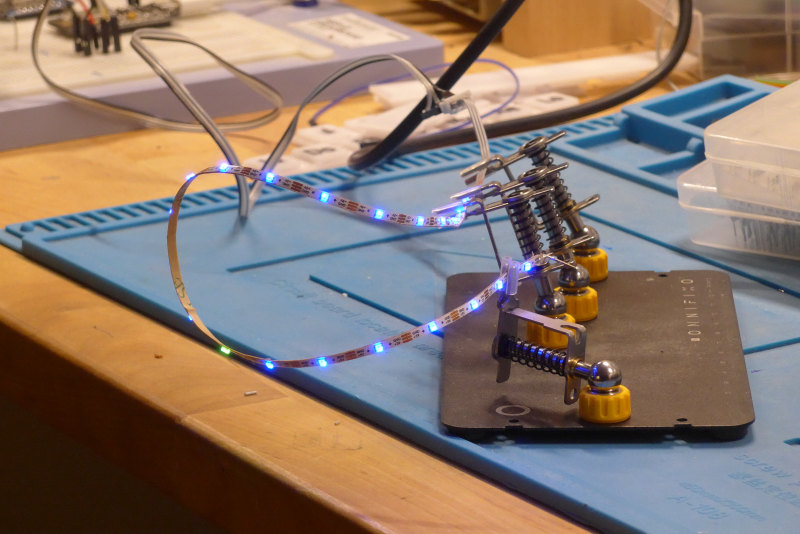
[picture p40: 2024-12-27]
LED-Buttons Mod/Pictures/TestRig.png

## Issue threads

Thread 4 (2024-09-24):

New use for rightmost 16 pads

Miq1, 2024-09-24:
The pads right of the scale notes are used to display the notes of the last pressed chord. Makes no sense to me most of the time. Except when in chromatic mode the rightmost 4 or 5 rows of pads are wasted.

What about being able to assign MIDI messages to these pads? One could switch instruments, mute and start tracks or even map one pad aftertouch to mod wheel or filter cutoff etc.

Miq1, 2024-12-08:
Outdated by the recent developments. 🎈

Closed 2024-12-08.

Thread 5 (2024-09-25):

MIDI panic does not work

Miq1, 2024-09-25:
### Version

alpha4d

### What is the issue?

The mechanism Fred described to cut off all MIDI traffic (panic) by pressing the 4 outer corner pads simultaneously seems not to work at all. I had several situations where hanging notes were not cut off.

Frudah, 2024-11-05:
This has been dealt with. Mid panic is now implemented with the two octave change buttons rather than the 4 corners. It should work in scales and classic mode. Will add to other modes shortly. Previous issue was I was sending all notes off messages on all channels, but was not clearing the active note buffers. So, the next key that was pushed would hang notes if the notes were ones that had been turned off, but not cleared in the buffers.

tracking has been improved so this should be less, if not a non-existent midi panic problem.

Closed 2024-11-05.

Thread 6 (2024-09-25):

Hanging notes

Miq1, 2024-09-25:
### Version

alpha4d (for alpha4f still valid)

### What is the issue?

When simultaneously pressing the outer 4 corner keys (to release all keys - MIDI panic) notes are triggered and left ON.

Some are releasable by pressing the same note again, others aren't.

Frudah, 2024-11-05:
Note tracking system improved. MIDI panic function improved. New method is the two octave buttons. Note tracking buffers are now being cleared instead of just sending note off messages on all channels.

Closed 2024-11-05.

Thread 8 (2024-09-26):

Switching between easy and standard chord modes requires three button presses

Miq1, 2024-09-26:
### Version

alpha4d

### What is the issue?

When in Scales mode, pressing the middle round button is supposed to toggle between easy and standard chords. It does, but only if pressed twice. Standard to easy chords needs just one press.

Frudah, 2024-11-05:
This is a feature. Previously, the first two modes were duplicated, both being chromatic chords. Now, it’s 6 chord layout, diatonic chords and chromatic chords. Two layouts will look identical, Burt the chords loaded are not. I will need to add layout names to differentiate layouts that look identical.

Frudah, 2024-11-05:
… and closing

Closed 2024-11-05.

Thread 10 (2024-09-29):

Pitchbend is not cut off with NOTE OFF?

Miq1, 2024-09-29:
### Version

alpha4d

### What is the issue?

ShowMIDI shows that the pitchbend signal is continuing after NOTE OFF.

It is disputable if pitchbend bound to a key is sensible. I can see the intention, but it at least does not fit my habits 🤣

Frudah, 2024-11-05:
Tested code was left in, since removed and verified.

Closed 2024-11-05.

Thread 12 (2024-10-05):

Note keys lighting

Miq1, 2024-10-05:
### Version

alpha4d

### What is the issue?

I find myself often wondering what octave I had set. To help me remembering I had some ideas:
- always illuminate C3 in white. Brighter, when part if the current scale, dim when not. This obviously applies to chromatic mode and otherwise scales with C in it only
- cut off lighting of notes not existing (below C-1 and above B9)
- make octave up/down keys dim if they would have no effect (since the upper row already is octave 9 or the bottom row is -1)

Smelter, 2024-11-09:
That feeds into my External LED slave strip board idea. I'll be in touch.

Frudah, 2025-02-01:
New pop-ups / screen messages will indicate octave positioning, alleviating doubt/guesswork.

Closed 2025-02-01.

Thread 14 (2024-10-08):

Install quirk / Key illumination levels / Key consistency

Smelter, 2024-10-08:
### Version

alpha4d

### What is the issue?

#### 1. LED remains lit after update and Shutdown
Shutdown via menu screen after install of Alpha4d.333
Current draw present with Bot LHS LED lit.
This is only for power down via menu shutdown after the firmware update, unplug and power up, and it does not repeat on the next shutdown.
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

#### 2.No_Hi-light
The high brightness does not change from the previous (mid?) setting.
Incremental light levels from the low end but the top two are the same.
https://github.com/user-attachments/assets/68d6743d-6e88-4873-9c1d-c24235ee1e7b

#### 3. No_Consistency
Inconsistent tones has two issues.
1) I can't get a button to repeat or another to replace it while it is sounding, its as though once triggered it holds on until the envelope is finished.
2) The buttons will trigger their LEDs without sounding for light touch, I have tried all the sensitivity ranges for a noise threshold of 21.
For the current firmware it doesn't function as a keyboard were you can just play nots reliably, which makes it not usable for live performances which has been requested elsewhere.
https://github.com/user-attachments/assets/0ebf6778-59ad-4021-8f67-db3088ed0455

Frudah, 2024-11-05:
Highlights should all be consistent. There are some places I previously set them as a constant, but I believe I have removed all constants and changed to the HighLight variable. I made sure to refresh the led buffer before the shutdown procedure finishes, so you shouldn’t see any more lights stuck on.

the other issues sounds like the note hanging/note tracking issue which has also been resolved for scales/classic.

Closed 2024-11-05.

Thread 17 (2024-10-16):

Manic MIDI Channel 1

Smelter, 2024-10-16:
### Version

alpha4g

### What is the issue?

MIDI channel 1 has continuous data output. On MIDI jack (USB MIDI yet to be tested)
(Previous channel 16 problem now solved)

Note off codes sent for C -1 and Eb-0 or 1 (digits are overlaid)

This starts immediately on power up and continues while powered up.

MIDI channel 1 sends note info to my Synth and generates an audio output.

https://github.com/user-attachments/assets/3806870a-1985-4d11-ac3a-0abb27f3659e

Smelter, 2024-10-28:
Also persists on Alpha 5

Smelter, 2024-10-28:
Also persists on Alpha 5

https://github.com/user-attachments/assets/619431fa-00e6-4820-aaec-16f8e8342737

Frudah, 2024-11-05:
This has been fixed with removing test code that was flooding the usart buffer.

Closed 2024-11-05.

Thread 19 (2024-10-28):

Alpha 4g sign off

Smelter, 2024-10-28:
### Version

alpha4g

### What is the issue?

About screen shows to be "Alpha 5". Looks like someone got ahead of themselves in the version control ;-)
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

Save settings screen has a language query. At lest the black screen of death is not shown as previous version.
https://github.com/user-attachments/assets/115739a1-19fd-4d91-945a-e3fb0ffbf0eb

Miq1, 2024-10-28:
4g is the past 😉

Smelter, 2024-10-30:
It may be the past, but it was the best version for removing the LEDs
flickering. I might just be going back to it!

On Mon, 28 Oct 2024, 16:12 Michael Harwerth, ***@***.***>
wrote:

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

Closed 2024-10-28.

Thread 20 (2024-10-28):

Flickering LEDs are back.

Smelter, 2024-10-28:
### Version

alpha5

### What is the issue?

These are LEDs on the Left Hand End under the 'C' label.
Looks like a retro step as all was well with 4g.

https://github.com/user-attachments/assets/8d77b9f2-49b6-4f30-bab1-952cadc8f248

amaskell999, 2024-11-04:
I think this has been fixed in alpha5.1.A

Miq1, 2024-11-05:
Does rather look like the DMA quirk is back Fred had earlier.

Frudah, 2024-11-05:
If you reset your settings on install of the new firmware I believe the default is 40 for noise floor. I can make the lower limit higher for roll over… or assign it to a sub menu so it allows up and down so there is no roll over. 5.1.a does fix it I believe. The buffer function is still the same. I plan on improving it. What I did find, was the strummer1 was always active and cycling and it was lagging down the led timing.

I have now made it so the strummer isn’t activated until a button with strum is pressed and is deactivated after a press. I’m sure I can optimize the strummer a bit to not make it as resource intensive later.

Frudah, 2024-11-05:
… and closed

Frudah, 2024-11-07:
I also found that strummer 2 and strummer 3 modules were continually looking to make sure there were no unresolved strum notes to turn off, robbing the chip of thousands of clock cycles per midi pulse. 5.2 has this fixed and should further reduce any of these erroneous pulses being presented.

Closed 2024-11-05.

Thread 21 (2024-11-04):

LED splatter pattern for single key press.

Smelter, 2024-11-04:
### Version

alpha5.1

### What is the issue?

I have tried multiple sensitivity and noise threshold settings with no change.

https://github.com/user-attachments/assets/e55cc6d0-6709-494d-b4df-199bfa00ce4b

Miq1, 2024-11-04:
This is a feature Fred announced with alpha5. You can switch it off in the Settings.

Smelter, 2024-11-04:
I didn't expect it to be on by default. Looks like we need a user
preference save function :-)

On Mon, Nov 4, 2024 at 4:27 PM Michael Harwerth ***@***.***>
wrote:

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

Frudah, 2024-11-07:
it is there. close to bottom of settings... select "off". put it on by default so you'd see it and can disable it if you don't like it. make sure to use shutdown function to power off. this will save settings. settings are not saved unless "shutdown" is used... or it is saved and recalled from a user set.

Smelter, 2024-11-07:
All perfectly reasonable. And yes I get it now. I know we are still at the Alpha testing stage, but when something appears, and its set on at start up, my brain says "that's new, do I like it, can I turn it off and it stays off" Consider my ramblings as innocent and exploring. I have beta tested other software and heard back that no one else has spotted that, which has lead to  interesting developments. So these are not complaints just observations.

Closed 2024-11-04.

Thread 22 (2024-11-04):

One key press, two notes sound

Smelter, 2024-11-04:
### Version

alpha5.1

### What is the issue?

Appears to be some form of "switch bounce" generated in the firmware.
https://github.com/user-attachments/assets/9d682cbc-9c11-49e7-a965-63463a2d1270

Miq1, 2024-11-04:
No bug, but a feature. Fred described it when publishing alpha5. You can switch it off in the Settings.

Smelter, 2024-11-04:
I have tried changing the sensitivity settings with inconsistent results.
The higher the numerical range the longer the gap between the initial note and the bounce note.

Smelter, 2024-11-04:
Clock set to 'E' & 'IO' clears the problem. So the setting of 'IS' is the problem!

Smelter, 2024-11-04:
Hokey Cokey?

On Mon, Nov 4, 2024 at 4:24 PM Michael Harwerth ***@***.***>
wrote:

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

Frudah, 2024-11-05:
Is this with a daw or midi instrument? Which kind please. I made the Internal Only clock because I found sending the clock to my Moog was producing issues. I may have actually been wrong, as I also found an issue with the chord note sequencers to the Moog or DAW without it.

Smelter, 2024-11-06:
> Is this with a daw or midi instrument? Which kind please. I made the Internal Only clock because I found sending the clock to my Moog was producing issues. I may have actually been wrong, as I also found an issue with the chord note sequencers to the Moog or DAW without it.

Observation is for MIDI over DIN via synth. This is my preference as I have a project waiting for key colours being declared in a SYSEX message, to have physical LEDs over the synth's keys.

Frudah, 2024-11-07:
I know you sent me a few videos. Any way you can send me the sysex messages you want? if not, can you send the video links again?

Frudah, 2024-11-09:
should be fixed for 5.2. reopen if you still have issues.

Closed 2024-11-09.

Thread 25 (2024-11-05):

Chord/ note sequencers hanging

Frudah, 2024-11-05:
### Version

alpha5.1

### What is the issue?

I don’t know who wrote this, but the chord sequencers produce hanging notes. Drum sequencer and master sequencer work properly.

Closed 2024-11-09.

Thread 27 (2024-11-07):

Key 1 in key blocks 5+6 triggered by other keys of those blocks

Miq1, 2024-11-07:
### Version

alpha5.1.A

### What is the issue?

Scales mode. The top left key in the 4x4 grid blocks #5 and #6 is lit white and stays on, if any other key in that grid block is pressed. Pressing the top left key itself will clear the white, as will any chord key on the left keyboard.

The other notes in the 4x4 block have no white indication when pressed.

Frudah, 2024-11-09:
should be fixed with 5.2. Code overhaul missed/lost some tracking variables, but they are back. Reopen if you find this is not the case.

Closed 2024-11-09.

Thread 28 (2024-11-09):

Light Board 'X' locks

Smelter, 2024-11-09:
### Version

alpha5.2

### What is the issue?

5v2a  "Light Board" setting once set won't unset locally (it will Reset) but colours are different at each stage on LHS.

Default colours on fresh install >
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

Colours when "Light Board" is selected ( 'X' ) >
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

Colours when "Reset" is run >
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

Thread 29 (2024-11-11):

Top line text overlap

Smelter, 2024-11-11:
### Version

alpha5.3

### What is the issue?

Mode line text string length needs checking for overlap with blinking filled circle.
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

Frudah, 2024-12-14:
Condensed key and scale name. Longer names may still be cut off, but priority will be given to bpm display.

Closed 2024-12-14.

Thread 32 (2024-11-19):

No Shut Down 6v0

Smelter, 2024-11-19:
### Version

alpha5.4

### What is the issue?

Alpha 6 : Shutdown menu keypress has no action.
Are the settings saved?

Menu screen will blank out after a few seconds. Missed that on the recording.

Smelter, 2024-11-25:
Progress comment from developer in 'Messenger Chat' :- "it does save before whatever it doesn't do"
So presumably its a screen menu glitch and is safe to power down after execution.

Miq1, 2025-01-07:
Pushed up to "Bug", since settings are not saved any more with 6.6.

Miq1, 2025-02-01:
'System->Save All' works now (Stechapfel.6.6.Fa)

'System->Shutdown' is bringing the board into some limbo - middle keys and display remain lit, as do the top row buttons.

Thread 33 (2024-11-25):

Aftertouch always has pressure 0

Miq1, 2024-11-25:
### Version

alpha 6.1

### What is the issue?

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
Aftertouch messages all have pressure set to 0, regardless of the pressure applied.

Frudah, 2024-11-28:
fixed 6.1

Closed 2024-11-28.

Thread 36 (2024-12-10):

Chord display flickering/invisible

Miq1, 2024-12-10:
### Version

alpha6.5F

### What is the issue?

The chord or note display screen (Main menu, left arrow button) is unreadable. There is a constant, but flickering "-2" left in the middle, while chords/notes only will shine up partly and corrupted.

@Smelter: you found it originally :wink:

Miq1, 2024-12-14:
Update on version TallFescue6.5999: The "-2" is gone, but the display still is flickering and incomplete.

Smelter, 2024-12-14:
The -2 is gone but the user name it replaced has not returned. The user name is only seen on power up when the light show that refusers to be able to turned off runs.

Frudah, 2025-02-01:
still minor flickering / screen refresh, but IMHO, readable and functional.

Closed 2025-02-01.

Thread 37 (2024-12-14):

Octave keys on right keyboard confused

Miq1, 2024-12-14:
### Version

TallFescue.6.5999

### What is the issue?

When switching root note/scales etc. the octave keys on the right keyboard will be arranged horizontally. Using "octave up" the arrangement will flip to vertically. The initial "octave down" key is dead further on, even if it is lit with a chord note or in a chromatic layout.

Miq1, 2024-12-19:
Addition: with Live Mode on, switching octaves will disable the rightmost two columns of chord note keys.

Frudah, 2025-02-13:
Octave keys should be fixed in all "Right" layouts. As always, re-open if your testing finds otherwise.

Closed 2025-02-13.

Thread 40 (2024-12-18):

Hard strike can produce multiple midi events

distrakt, 2024-12-18:
### Version

TallFescue.6.5999

### What is the issue?

I did this in "USER MODE", but likely this happens in other modes too.

A hard fast strike (like a drumming tap) can produce multiple key on/key offs. The printout below includes time stamps in microseconds. We can see it's more likely to happen on hard strike (6b and higher) and if it's very brief.

```
FRED:FB: 1642560339 90 05 6b
FRED:FB: 1642567488 80 05 00
FRED:FB: 1642571472 90 05 5d
FRED:FB: 1642744616 80 05 00

FRED:FB: 1648271776 90 16 05
FRED:FB: 1648504943 80 16 00

FRED:FB: 1664965023 90 19 73
FRED:FB: 1665178429 80 19 00

FRED:FB: 1671630723 90 19 75
FRED:FB: 1671679852 80 19 00

FRED:FB: 1674339034 90 19 77
FRED:FB: 1674390804 80 19 00

FRED:FB: 1676157987 90 19 77
FRED:FB: 1676161481 80 19 00
FRED:FB: 1676164242 90 19 46
FRED:FB: 1676204122 80 19 00
```

Frudah, 2024-12-21:
you may want to adjust the "Noise Floor" value in sensitivity. sounds like a cross talk issue fixable with adjusting the analog filter floor via the "Noise Floor" value being increased.

Miq1, 2024-12-21:
The remedy may work; it does not look like a cross talk issue, though, as it is always the same note triggered again. One possible reason could be the plastic contact sheet is slightly "bouncing" wenn hit hard enough, another would be an overflow of the velocity value when brought to the 0-127 range.

distrakt, 2024-12-21:
I'll experiment with the noise floor setting.
it does seem to be a "sometimes" thing. this morning I'm not seeing it happen. maybe i dont have enough static electricity from the day in me yet. I'll collect electrons during the day and try again.

Frudah, 2025-02-01:
should be fixed with new version 6.6Fa. please re-open if you find otherwise.

Frudah, 2025-02-01:
should be fixed with 6.6Fa. Unable to replicate in newest version. Please reopen if still occurring.

Closed 2025-02-01.

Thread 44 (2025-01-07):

Chord keys all red (numerous ways)

Miq1, 2025-01-07:
### Version

Rindfleisch... (internal)
### What is the issue?

Not repeatable every time, but when selecting a major scale, then switching back and forth between Aeolian (Minor) and Ionian (Major) sometimes all chord keys will go red:
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
These keys have no function at all.

A next switch to the other mode will restore the chord keys.

Miq1, 2025-01-11:
Happened as well when using the root key buttons. Must be something central.

Miq1, 2025-02-01:
Not reproducible any more.

Closed 2025-02-01.

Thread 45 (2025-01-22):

"5" key is a trapdoor into Pentatonic

Miq1, 2025-01-22:
### Version

TallFescue.6.5999

### What is the issue?

If pressing the "5" key once, you are trapped inside Pentatonic mode on the right hand keyboard. There is no other way out as the Scales menu.

I would expect the "5" key to toggle between Pentatonic and chromatic modes.

Side track: **if** you switched back to chromatic mode with the Scales menu, the "5" key will remain functionless until you pressed the "12" key at least once.

Miq1, 2025-01-24:
Fixed in Stechapfel6.6a, "12" brings you out of it.

Frudah, 2025-02-01:
need more info. The intention of the 5 key is to switch it permanently to pentatonic (no toggle).... with any of the modal keys, user slots... the '12' key .... or selecting a scale in the menu.

it is intended for only the user slots / '12' key to toggle back.

Miq1, 2025-02-01:
Now (Stechapfel.6.6.Fa) at least the mode buttons will bring you back.
The "12" button does change the layouts for Pentatonic mode using the same logic as in the "normal" scales - fine.
I will try to see the "5" button like another mode button for now.

Closed 2025-02-01.

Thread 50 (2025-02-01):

Note/chord display still needs some polishing

Miq1, 2025-02-01:
### Version

Stechapfel.6.6F

### What is the issue?

There are some artefacts disturbing the note/chord display (main menu, left arrow)

https://github.com/user-attachments/assets/093eac46-b89a-4900-ae11-f1047ca4274a

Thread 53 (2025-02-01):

After reboot middle buttons are all lit

Miq1, 2025-02-01:
### Version

Stechapfel.6.6F

### What is the issue?

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

I would expect the lights reflecting the last (saved) state. Pressing any of the buttons will do that.

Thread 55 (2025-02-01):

Better way to show chord notes in 'Live Update' mode

Miq1, 2025-02-01:
### Version

Stechapfel.6.6F

### What is the issue?

I would like to propose a different approach to the chord notes being shown on the right keyboard in the different layouts:

Given the chord Fmaj7 in octave 3 - notes are F3, A3, C4 and E4.

Let the note keys on the right light in white for a short period after the chord key is pressed:

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

The example is shown for the chromatic layout, but the principle will work in any layout.

This will help learning which keys are used in a chord, if the scales will remain at their root note position.

abdinfos, 2025-02-05:
Good idea but should not replace normal Live Update. Because of the isomorphic nature of the layout of the current Live Update keys layout which is also of interest in the first place. Could be a second Live Update mode.
By the way, why are the octave key in vertical layout on you drawing? It disturbs two octaves instead of one.

Miq1, 2025-02-05:
> By the way, why are the octave key in vertical layout on you drawing? It disturbs two octaves instead of one.

Fred has changed that a couple of times, faster than I could follow 😉 I do not know if he is finally decided now.

abdinfos, 2025-02-06:
On second thought, I see this more as a Chord Sense or Chord Show or whatever it's called, independent of Live Update. It could be enabled or disabled by setting.
It would come in very handy, whether for learning, guiding or even checking the operation of the chords generated by the left keyboard. For instance it could also be used to guide play by adding ephemeral notes to chords with the right hand, notes that you wouldn't have to add to chords with the center keys. Nice to vary your playing, adding a bass an octave lower while visualizing its position, guiding the melody, etc…
The pads concerned could perhaps flash as long as the notes played by the left keyboard are active (or as long as another left chord pad is pressed), or (and I think I prefer this) have a change of intensity (plus or minus).
What's more, this doesn't prevent you from keeping Live Update mode as it is now. On the other hand, if Live Update is not active, any unused keys should be used to complete the scales, making it easier to play chords, and should be taken into account by Chord Sense.

abdinfos, 2025-02-06:
> > By the way, why are the octave key in vertical layout on you drawing? It disturbs two octaves instead of one.
>
> Fred has changed that a couple of times, faster than I could follow 😉 I do not know if he is finally decided now.

I thought the octave keys were only in the vertical position with the guitar display, when in fact they are string shift keys, which makes sense

Miq1, 2025-02-06:
> I thought the octave keys were only in the vertical position with the guitar display, when in fact they are string shift keys, which makes sense

In fact they were at one time, but Fred managed to render the former octave down key useless in most other layouts 🤣
We will see what comes out at the end.

Frudah, 2025-02-13:
should be fixed now... (chord octave buttons). only the guitar layout is meant to be vertical...

will circle back on alternate live note update option.

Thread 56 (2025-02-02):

Light Board - access and use issues.

Smelter, 2025-02-02:
### Version

Stechapfel.6.6F

### What is the issue?

"Light Board" sub menu reads :
Mode : LIGHTBORD       - What are we going with here? with or without the letter A?
< Chromatic
All Lit >

Now the arrow entries in this menu are not consistent in response. I have been able to turn off all the LEDs in this menu and turn them back on.
Also I have been able to "X" and un"X" the top level menu listing.

The sub menu is time entry dependent, and returns to the same main menu position. (thank goodness, read on)
However for key entries 'O' '<' it exits to the rolling number. (can't remember what it is I read that is) press '>' and we are back to the sub menu with no time out. Press '>' at this screen and nothing happens, other than the number count is refreshed. Wait awhile and it times out back to the main menu but at the "Scales |>" entry, 8 steps up from the "Light Board |  X" entry, which if you press 'O' you are then locked into the sub menu where neither '<' or '>' works so you have to wait until the time out takes you back to the main menu.

And if that was not confusing enough. there is a surprise if you try to access the "Manual" sub menu, as you are back to the "Light Board" sub menu where pressing the 'O' key makes the sub menu title say "Scales" and further pressing of 'O' starts a scroll through colour pallet selections.

Looks like there are cross reference/links between menu entries and possible code re-use that it getting well confused.

Frudah, 2025-02-03:
Where is the button to give you the ‘Greatest bug tester award’?

Miq1, 2025-02-03:
Added it 😄

Smelter, 2025-02-03:
> Where is the button to give you the ‘Greatest bug tester award’?

Glad to be of service. Actually it's nice to use the methodical approach I used when employed, into my retirement. Just glad others know the music theory side for testing, that is what I bought the TB for, but coming without a manual and having issues, how was I to know how if it worked or even if it was doing it right?

Closed 2025-02-13.

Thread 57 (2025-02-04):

MIDI select - Cable 2 list entries shifted and one missing

abdinfos, 2025-02-04:
### Version

Stechapfel.6.6F

### What is the issue?

Settting / Midi Options / Ch out Left (or Right)
In the list, after Cable:1 Port:16 comes Cable:2 Port:2 instead of Port:1
Selecting it selects Port 1
Last entry that should be Cable:2 Port:16 is blanck but works as if normal and selects Port 16

Frudah, 2025-02-13:
Found issue. Was missing a "," in array :/   Closing. Will be fixed for next release. (post 6.6.0Fb)

Thank you for the feedback :)

Closed 2025-02-13.

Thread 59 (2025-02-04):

Clock settings - Enter settings leads to board freeze

abdinfos, 2025-02-04:
### Version

Stechapfel.6.6F

### What is the issue?

Try to enter Clock setting freezes the board
You can’t recover until you unplug

Frudah, 2025-02-05:
Fixed in my side… will be good for next upload. Will leave open until then.

Frudah, 2025-02-13:
Fixed as of 6.6.0Fb

Closed 2025-02-13.

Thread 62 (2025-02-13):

Advanced Sensitivity Settings: menu damaged

Miq1, 2025-02-13:
### Version

6.6.0 "Stechapfel"

### What is the issue?

In the Advanced Sensitivity Settings menu, the 'Offset' lines for the 2nd to 4th quarters are overwritten by a dashed line.

BTW: That menu has 22 entries. If adjusting some values for the quarters further right, one has to step through a lot of menu lines again and again if trying to see the resulting curve in between.

Two complementing solutions came to my mind:

1. After any modification of a value, show the curve until any button is pressed
2. Add another menu level like 'Quarter 1', 'Quarter 2' etc. with the respective 'Type', 'Power', 'Base', 'Offset' and 'Slope' Entries in a sub-menu.

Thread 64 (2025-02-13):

Right-side Octave keys not working correctly

Miq1, 2025-02-13:
### Version

6.6.0 "Stechapfel"

### What is the issue?

When using the "12" button to switch layouts on the right-side keyboard, funny things are happening. I was not yet able to find a rule, but you easily will get these effects after a while:
1. whole right-side keyboard muted until layout is changed again
2. octave keys vertical again in non-Guitar layouts, horizontal in Guitar instead
3. the key in the top row, second from the right is muted

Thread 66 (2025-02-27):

System/Shutdown

Smelter, 2025-02-27:
### Version

6.6.0 "Stechapfel"

### What is the issue?

6v6Fc

Selection (centre round button) of "System" blanks all the LEDs.  A given time (out) restores them.
Selection (> right arrow key) of "System" gives a sub menu where "Shutdown" is selectable,. Blanks LEDs but LCD menu remains lit with last screen.

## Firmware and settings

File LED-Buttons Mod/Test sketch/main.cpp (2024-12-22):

#include <Arduino.h>

#include <FastLED.h>
#include "Buttoner.h"

///////////////////////////////////////////////////////////////////////////////////////////
//
// Move a white dot along the strip of leds.  This program simply shows how to configure the leds,
// and then how to turn a single pixel white and then off, moving down the line of pixels.
// 

// How many leds are in the strip?
#define NUM_LEDS 48

// For led chips like WS2812, which have a data line, ground, and power, you just
// need to define DATA_PIN.  For led chipsets that are SPI based (four wires - data, clock,
// ground, and power), like the LPD8806 define both DATA_PIN and CLOCK_PIN
// Clock pin only needed for SPI based chipsets when not using hardware SPI
#define DATA_PIN  D6
// #define CLOCK_PIN 13

Buttoner toggle(D5, LOW, true);
uint8_t mode = 0;
const uint8_t MAXMODE = 2;

// This is an array of leds.  One item for each led in your strip.
CRGB leds[NUM_LEDS];

const uint16_t usedLED[] = {
   0, 2, 3, 6, 7, 10, 11, 14, 15, 18, 19, 22, 23, 26, 27, 30, 31, 34, 35, 38, 39, 42, 44, 46, 47, 9999 
};

// This function sets up the ledsand tells the controller about them
void setup() {
  // sanity check delay - allows reprogramming if accidently blowing power w/leds
  delay(2000);

  Serial.begin(115200);
  while(!Serial) {
    Serial.printf(". ");
  }
  Serial.printf("_OK_\n");

  FastLED.addLeds<WS2812B, DATA_PIN, RGB>(leds, NUM_LEDS);  // GRB ordering is typical
  FastLED.setBrightness(27);
}

// This function runs over and over, and is where you do the magic to light
// your leds.
void loop() {
  static unsigned long T3 = 0;
  static unsigned long T2 = 0;
  static uint8_t ONOFF = 0;
  static uint16_t point = 0;

  T2 = millis();
  if(toggle.update()) {
    if(toggle.getEvent() == BE_CLICK) {
      mode++;
      if (mode > MAXMODE) {
          mode = 0;
      }
      Serial.printf("mode=%u\n", mode);
    }
  } 

  if (mode == 0 || mode == 1) {
    if (T2 - T3 > 2000) {
      if (ONOFF == 0) {
        CRGB randomcolor_1  = CHSV(random(192), 255, 255);
        CRGB randomcolor_2  = CHSV(random(192), 255, 255);
        if (mode == 0) {
          for(int led = 0; led < NUM_LEDS; led++) {
            leds[led] = randomcolor_1;
            if (random(8) == 1) leds[led] = randomcolor_2;
          }
        } else {
          for(auto led : usedLED) {
            if (led < 9999) {
              leds[led+1] = randomcolor_1;
              if (random(8) == 1) leds[led+1] = randomcolor_2;
            }
          }
        }
      } else {
        for(int led = 0; led < NUM_LEDS; led++) {
          // Turn our current led back to black for the next loop around
          leds[led] = CRGB::Black;
        }
      }
      FastLED.show();
      T3 = millis();
      ONOFF = !ONOFF;
    }
  } else if (mode == 2) {
    if (T2-T3 > 500) {
      for(int led = 0; led < NUM_LEDS; led++) {
        leds[led] = CRGB::DarkBlue;
      }
      leds[point] = CRGB::DarkGoldenrod;
      point++;
      if (point >= NUM_LEDS) point = 0;
      FastLED.show();
      T3 = millis();
    }
  }
}

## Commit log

2024-09-16 Add debug prints
2024-09-18 Another scaling round
    [Sensitivity.ods]
2024-09-18 Improved weight.pl and results
    [Sensitivity.ods]
2024-10-01 Center Pad Mod initial commit
    [TB-Parts-Arrow_Left_Right.stl, TB-Parts-Arrow_up_down.stl, TB-Parts-Center.stl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]
2024-10-01 Section on sensors added
2024-10-12 Top Row Mod #1
    [5-12_Buttons_basic.stl, 5-12_Letters_basic.stl, C-F_Buttons_basic.stl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]
2024-10-12 Sensor plates
2024-10-12 STLs added
    [5-12_Buttons_basic.stl, 5-12_Letters_basic.stl, C-F_Buttons_basic.stl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]
2024-10-12 Remove duplicates
    [5-12_Buttons_basic.stl, 5-12_Letters_basic.stl, C-F_Buttons_basic.stl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]
2024-10-13 Print settings
2024-10-13 OpenSCAD explanations
    [BasicButtons.scad]
2024-10-13 Add assembly
2024-10-14 Add alternative Button set
    [BasicButtons.scad, M1-M7_AltButtons_basic.stl, M1-M7_AltLetters_basic.stl]
2024-10-27 Delete Sensitivity directory
    No longer necessary
    [Sensitivity.ods]
2024-12-13 Another grass... 😁
2024-12-19 Tool making
    [StanzlehreRund-Cut.stl, StanzlehreRund-Press.stl, StanzlehreRund-Punch.stl]
2024-12-19 Add STL files
2024-12-27 Initial push
    [5-12_Buttons_lit.stl, 5-12_Letters_lit.stl, BendingTool.stl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]
2024-12-28 Start wiring
2024-12-28 Melt-in M3 threads
2024-12-28 Rail PCB
2024-12-28 Main Board
2024-12-28 Main board connector
2024-12-28 Main board finished
2024-12-28 Case cutouts
2024-12-28 PCB placement
2024-12-28 Connector PCB in place
2024-12-28 Boards fixed
2024-12-28 Left cable
2024-12-28 Pin fixed
2024-12-29 Right stripe pin
2024-12-29 Right stripe cable
2024-12-29 LED channel
2024-12-29 Insert part 1
2024-12-29 LED stripe finalized
2024-12-29 Buttons in
2024-12-29 DATA cable
2024-12-29 Plate join
2025-01-01 New bolts
2025-01-04 New STLs V1.1
    [2ndLeftButtons.stl, 2ndLeftLetters.stl, 2ndRightButtons.stl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]
2025-01-05 Revised button STLs and OpenSCAD script
    [2ndLeftButtons.stl, 2ndLeftLetters.stl, 2ndRightButtons.stl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]
2025-01-06 Fix minor fittings
    [TBLid-LeftKB.stl, TBLid-Plate.stl, TBLid-RightKB.stl]
